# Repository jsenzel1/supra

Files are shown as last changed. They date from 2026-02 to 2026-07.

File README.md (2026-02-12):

# SUPRA
 [SUPRA](https://suprasynth.site/)

is multimode Eurorack module with 4 different experiments in long term time. you can run up to 2 modes at once. use the 4 way joystick and buttons to interact with the modes on the oled




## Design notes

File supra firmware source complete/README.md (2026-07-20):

# supra
supra synth

# NOTES 

note that the whole repo uses old naming conventions 

SQUIGL = STAMP 
SEQO = ABACUS
MORSD = CRYPTEX 
MELO = CHIME

Lots of stuff here is very messy and unoptimized 

## BUILDING

The firmware source and the library code it uses are included directly in this
directory. `u8g2/csrc`, `pico-littlefs/littlefs-lib`, and
`pico-littlefs/stdinit-lib` are vendored so this directory does not rely on
Git submodules.

Install the ARM embedded toolchain and Raspberry Pi Pico SDK, then point CMake
at the SDK. This source has been tested with Pico SDK 2.2.0.

```sh
cmake -S . -B build -DPICO_SDK_PATH=/path/to/pico-sdk
cmake --build build --parallel
```

The flashable firmware is written to `build/supra.uf2`.

AI DISCLOSURE 

This was a super ambitious project for me and parts of it required me to get a little beyond my abilities as a software engineer. I used AI for parts of the programming, I'm not sure how I feel about. I don't use AI to ideate or assist with design decisions, because I don't like doing that. I don't use it to whole cloth create something, because I don't like that. It's really nice to be able to offload tasks that I truly don't care about or have any artistic interest in how their done (Ie, 2 different ways to dim an LED, which I will explain later). Part of me wonders if it would have been better to be less ambitious and write more by hand, but that feels like its over emphasizing purity. Everything was at least prototyped by hand initially. most of the use of AI for programming was for stuff like the following situations: 

I had a lot of trouble using the DAC in supra with RP350 (my main chip) and after lots of troubleshooting I ended up using a proprietary driver that AI wrote to interface with the DAC because it worked where off the shelf libraries didn't (writing that myself would have been incredible hard, taken a long time, and not have been knowledge I would need in the future) 

I realized that because of a small quirk in the way I set up the hardware on the LEDs that one of them would not have dimming capabilities unless I redesigned and ordered a new batch, or if I implemented a software solution using PIO which is a more advanced feature of my main chip that I haven't gone into or learned about yet. So I had AI write it to save the time and materials of a new batch. 

I used AI to rewrite parts of the code that were innificient and to implement multithreading which I tried to do on my own but failed and was frustrated since It was a lot of work, and the only thing it would do is make things run smoother, so I wasn't doing anything artistic or interesting design wise. I decide dto allow myself to offload that task 

etc. etc.  

you will notice AI comments around the repo as I used AI to implement some features on many modes like self clocking etc. which would have been out of scope to add myself late in production

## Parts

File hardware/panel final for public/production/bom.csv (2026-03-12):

Designator | Footprint | Quantity | Value | LCSC Part #
C1, C6, C7 | 0402 | 3 | 100n | C1525
C2, C3, C4, C5 | 0402 | 4 | 100p | C1546
DAC1 | MSOP-10_3x3mm_P0.5mm | 1 | MCP4728 | C478093
J1, J2 | PinHeader_1x06_P2.54mm_Vertical | 2 | Conn_01x06_Pin
R1, R10, R13, R14, R2, R5, R6, R9 | 0402 | 8 | 100K | C25741
R11, R15, R3, R7 | 0402 | 4 | 270K | C170277
R12, R16, R4, R8 | 0402 | 4 | 1K | C11702
U1 | SOIC-14_3.9x8.7mm_P1.27mm | 1 | TL074 | C6963

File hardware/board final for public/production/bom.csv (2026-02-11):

Designator | Footprint | Quantity | Value | LCSC Part #
BT1 | BatteryHolder_Keystone_3000_1x12mm | 1 | Battery_Cell | C964818
C1, C15, C17, C18, C19, C2, C20, C21, C22, C23, C24, C28, C3, C30, C31, C4, C5 | 0402 | 17 | 100n | C1525
C10, C11, C12, C29 | 0402 | 4 | 10u | C15525
C16, C25, C26, C27 | 0402 | 4 | 4.7u | C23733
C8, C9 | 0402 | 2 | 27p | C1557
D1, D2 | D_SOD-123 | 2 | 5819 | C8598
D10, D11, D12, D13, D14, D15, D16, D17 | D_SOD-323 | 8 | BAT43W-V | C134399
D18 | LED_PLCC_2835 | 1 | Lselect | C7500124
D19 | LED_PLCC_2835 | 1 | Rselect | C7500124
D3, D4 | D_SOD-123 | 2 | SM4001 | C151781
D5, D7 | LED_PLCC_2835 | 2 | R2 | C7500124
D6 | LED_PLCC_2835 | 1 | L2 | C7500124
D8 | LED_PLCC_2835 | 1 | L1 | C7500124
DAC1 | MSOP-10_3x3mm_P0.5mm | 1 | MCP4728 | C108207
F1, F2 | 0805 | 2 | SMD0805P010TF polyfuse | C20975
J1 | _Jack_3.5mm_QingPu_JACK_ANCHOR | 1 | out 3
J10, J6, J7, J9 | _Jack_3.5mm_QingPu_JACK_ANCHOR | 4 | AudioJack2
J14 | _Jack_3.5mm_QingPu_JACK_ANCHOR | 1 | out 1
J2 | _Jack_3.5mm_QingPu_JACK_ANCHOR | 1 | out 2
J3 | USB_C_Receptacle_G-Switch_GT-USB-7010ASV | 1 | USB_C_Receptacle_USB2.0 | C2988369
J4 | PinHeader_2x05_P2.54mm_Vertical | 1 | Conn_02x05
J5 | PinSocket_1x04_P2.54mm_Vertical | 1 | OLED DISP
J8 | _Jack_3.5mm_QingPu_JACK_ANCHOR | 1 | out 4
L1 | L_pol_2016 | 1 | 3.3u | C42411119
R1, R10, R13, R14, R17, R20, R28, R4, R5, R6, R9 | 0402 | 11 | 1k | C11702
R11, R15, R3, R7 | 0805 | 4 | 400k
R12, R16, R2, R37, R38, R40, R42, R8 | 0402 | 8 | 100k | C25741
R18, R19 | 0402 | 2 | 5.1k | C25905
R21, R22, R30, R31, R33 | 0402 | 5 | 10k | C25744
R23 | 0402 | 1 | 33 | C25105
R24, R25 | 0402 | 2 | 27 | C25100
R26, R27 | 0402 | 2 | DNF
R29 | 0402 | 1 | 1k
R32, R34, R43, R44 | 0402 | 4 | 3.3k | C25890
R35, R36, R39, R41 | 0402 | 4 | 470 | C25117
R46, R47 | 0402 | 2 | 100r | C25076
S1 | sw_nav_5waySUPRA | 1 | JS5208
SW1 | SW_PUSH_6mm | 1 | btnBOOT
SW2 | SW_PUSH_6mm | 1 | btnA
SW3 | SW_PUSH_6mm | 1 | btnB
SW4 | SW_PUSH_6mm | 1 | btnHand
U2 | SOT-89-3 | 1 | LD1117S33CTR | C81768
U3 | SOIC-8_3.9x4.9mm_P1.27mm | 1 | PCF8523T | C2651516
U5 | SON50P300X200X60-9N | 1 | W25Q128JVS | C2843335
U6 | RP2350-QFN-60-1EP_7x7_P0.4mm_EP3.4x3.4mm_ThermalVias | 1 | RP2350_60QFN | C42411118
U7 | SOIC-14_3.9x8.7mm_P1.27mm | 1 | OPA1679 | C2878631
Y1 | Crystal_SMD_3225-4Pin_3.2x2.5mm | 1 | X322512MSB4SI (mini 12MhZ crystal) | C20625731
Y2 | Crystal_SMD_3215-2Pin_3.2x1.5mm | 1 | Crystal DST310S 32.768KHz | C93232

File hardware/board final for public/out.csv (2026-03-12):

Reference | Value | LCSC | Datasheet | Footprint | Qty | DNP | JLC
R29 | 0 |  | ~ | Resistor_SMD:R_0402_1005Metric | 1
C8,C9 | 27p | C1557 | ~ | Capacitor_SMD:C_0402_1005Metric | 2
C1,C15,C17,C18,C19,C20,C21,C22,C23,C24,C28,C30,C31 | 100n | C1525 | ~ | Capacitor_SMD:C_0402_1005Metric | 13 |  | -- mixed values --
C2,C3,C4,C5 | 100nf | C1525 | ~ | Capacitor_SMD:C_0402_1005Metric | 4
L1 | 3.3u | C695126 | ~ | RP2350_60QFN_minimal:L_pol_2016 | 1
C16,C25,C26,C27 | 4.7u | C23733 | ~ | Capacitor_SMD:C_0402_1005Metric | 4
C10,C11,C12,C29 | 10u | C25741 | ~ | Capacitor_SMD:C_0402_1005Metric | 4
R24,R25 | 27 | C25100 | ~ | Resistor_SMD:R_0402_1005Metric | 2
R23 | 33 |  | ~ | Resistor_SMD:R_0402_1005Metric | 1
R32,R34,R43,R44,R46,R47 | 100r | C25076 | ~ | Resistor_SMD:R_0402_1005Metric | 6
R35,R36,R39,R41 | 470 | C25117 | ~ | Capacitor_SMD:C_0402_1005Metric | 4
R1,R4,R5,R6,R9,R10,R13,R14,R17,R20,R28 | 1k | C11702 | ~ | -- mixed values -- | 11
R18,R19 | 5.1k | C25905 | ~ | Capacitor_SMD:C_0402_1005Metric | 2
D1,D2 | 5819 | C8598 | ~ | Diode_SMD:D_SOD-123 | 2
R30,R31,R33 | 10K | C25744 | ~ | Capacitor_SMD:C_0402_1005Metric | 3
R21,R22 | 10k | C25744 | ~ | Capacitor_SMD:C_0402_1005Metric | 2
R2,R8,R12,R16 | 100k | C25741 | ~ | Capacitor_SMD:C_0402_1005Metric | 4
R37,R38,R40,R42 | 100K | C25741 | ~ | Capacitor_SMD:C_0402_1005Metric | 4
R3,R7,R11,R15 | 400k |  | ~ | Capacitor_SMD:C_0402_1005Metric | 4
J6,J7,J9,J10 | AudioJack2 |  | ~ | Connector_Audio:_Jack_3.5mm_QingPu_JACK_ANCHOR | 4
D10,D11,D12,D13,D14,D15,D16,D17 | BAT43W-V | C134399 | http://www.vishay.com/docs/85660/bat42.pdf | Diode_SMD:D_SOD-323 | 8
BT1 | Battery_Cell | C964818 | ~ | Battery:BatteryHolder_Keystone_3000_1x12mm | 1
SW2 | btnA |  | ~ | Button_Switch_THT:SW_PUSH_6mm | 1
SW3 | btnB |  | ~ | Button_Switch_THT:SW_PUSH_6mm | 1
SW1 | btnBOOT |  | ~ | Button_Switch_THT:SW_PUSH_6mm | 1
SW4 | btnHand |  | ~ | Button_Switch_THT:SW_PUSH_6mm | 1
J4 | Conn_02x05 |  | ~ | Connector_PinHeader_2.54mm:PinHeader_2x05_P2.54mm_Vertical | 1
Y2 | Crystal DST310S 32.768KHz | C93232 | ~ | Crystal:Crystal_SMD_3215-2Pin_3.2x1.5mm | 1
R26,R27 | DNF |  | ~ | Resistor_SMD:R_0402_1005Metric | 2
U4 | ESP32-PICO-D4 |  | https://www.espressif.com/sites/default/files/documentation/esp32-pico-d4_datasheet_en.pdf | RPi_Pico:RPi_Pico_SMD_TH | 1
S1 | JS5208 |  |  | 4ms_Connector:sw_nav_5way | 1
D5,D8 | L1 |  | ~ | LED_SMD:LED_PLCC_2835 | 2
D6 | L2 |  | ~ | LED_SMD:LED_PLCC_2835 | 1
U2 | LD1117S33CTR | C81768 | http://www.st.com/content/ccc/resource/technical/document/datasheet/99/3b/7d/91/91/51/4b/be/CD00000544.pdf/files/CD00000544.pdf/jcr:content/translations/en.CD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 | Package_TO_SOT_SMD:SOT-89-3 | 1
D18 | Lselect |  | ~ | LED_SMD:LED_PLCC_2835 | 1
DAC1 | MCP4728 |  | http://ww1.microchip.com/downloads/en/DeviceDoc/22187E.pdf | Package_SO:MSOP-10_3x3mm_P0.5mm | 1 |  | C478093
J5 | OLED DISP |  | ~ | Connector_PinSocket_2.54mm:PinSocket_1x04_P2.54mm_Vertical | 1
U7 | OPA1679 |  | http://www.ti.com/lit/ds/symlink/opa1678.pdf | Package_SO:SOIC-14_3.9x8.7mm_P1.27mm | 1
J14 | out 1 |  | ~ | Connector_Audio:_Jack_3.5mm_QingPu_JACK_ANCHOR | 1
J2 | out 2 |  | ~ | Connector_Audio:_Jack_3.5mm_QingPu_JACK_ANCHOR | 1
J1 | out 3 |  | ~ | Connector_Audio:_Jack_3.5mm_QingPu_JACK_ANCHOR | 1
J8 | out 4 |  | ~ | Connector_Audio:_Jack_3.5mm_QingPu_JACK_ANCHOR | 1
U3 | PCF8523T | C2651516 | https://www.nxp.com/docs/en/data-sheet/PCF8523.pdf | Package_SO:SOIC-8_3.9x4.9mm_P1.27mm | 1
D7 | R2 |  | ~ | LED_SMD:LED_PLCC_2835 | 1
U6 | RP2350_60QFN |  |  | RP2350_60QFN_minimal:RP2350-QFN-60-1EP_7x7_P0.4mm_EP3.4x3.4mm_ThermalVias | 1
D19 | Rselect |  | ~ | LED_SMD:LED_PLCC_2835 | 1
D3,D4 | SM4001 | C151781 | http://cdn-reichelt.de/documents/datenblatt/A400/SMD1N400%23DIO.pdf | Diode_SMD:D_SOD-123 | 2
F1,F2 | SMD0805P010TF polyfuse | C20975 | ~ | Fuse:Fuse_0805_2012Metric | 2
J3 | USB_C_Receptacle_USB2.0 | C2988369 | https://www.usb.org/sites/default/files/documents/usb_type-c.zip | Connector_USB:USB_C_Receptacle_G-Switch_GT-USB-7010ASV | 1
U5 | W25Q128JVS | C2843335 | http://www.winbond.com/resource-files/w25q128jv_dtr%20revc%2003272018%20plus.pdf | Package_SO:SOIC-8_5.23x5.23mm_P1.27mm | 1
Y1 | X322512MSB4SI (mini 12MhZ crystal) | C9002 | ~ | Crystal:Crystal_SMD_3225-4Pin_3.2x2.5mm | 1

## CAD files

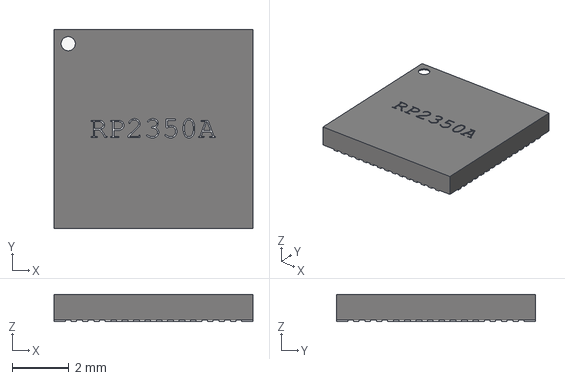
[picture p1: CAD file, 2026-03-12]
hardware/board final for public/RP2350_QFN60.step
7.00 x 7.00 x 0.95 mm

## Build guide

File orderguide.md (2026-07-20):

This is an ordering guide for SUPRA 
right now for internal use - but might be useful for people to see how it works 
note - if you need to order extra joysticks from adafruit its [this one](https://www.adafruit.com/product/504)

## STEP 1

order boards from JLC 
JLC boards and panels for production runs are always reorders to prevent alterations resulting in bricked runs 
more info and links for this coming, for now I'll probably be basically doing it 

## STEP 2 
order this cart from [mouser](https://www.mouser.com/Tools/Project/Share?AccessId=abbf7e4cee) 
you will have to select the items - this is for 100 modules, so the numbers can be changed accordingly 

PUBLIC NOTE: (this temp guide is for existing manufacturer ordering parts - so it doesn't include parts that are already stocked at their warehouse 
see [BOM](https://airtable.com/appK64nfCek7UE6Ky/shrHy2ZPqv2uyKhwK) for all parts 

## STEP 3

order this [display](https://www.buydisplay.com/i2c-white-1-3-inch-oled-display-module-128x64-arduino-raspberry-pi) from buydisplay 
note: fast shipping is extra but required for quick turnaround

## STEP 4 

order these [joystick toppers](https://www.amazon.com/uxcell-Silica-gel-Pushbutton-Tactile-Protector/dp/B07PGTZP9Z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) from amazon (RIP, literally cannot find them anywhere else and I have order lik $60 of various button toppers, these are the only that have worked at all) 

That should be it for now!

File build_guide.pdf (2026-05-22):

# Supra Build Guide

## 1: 5-way navigator

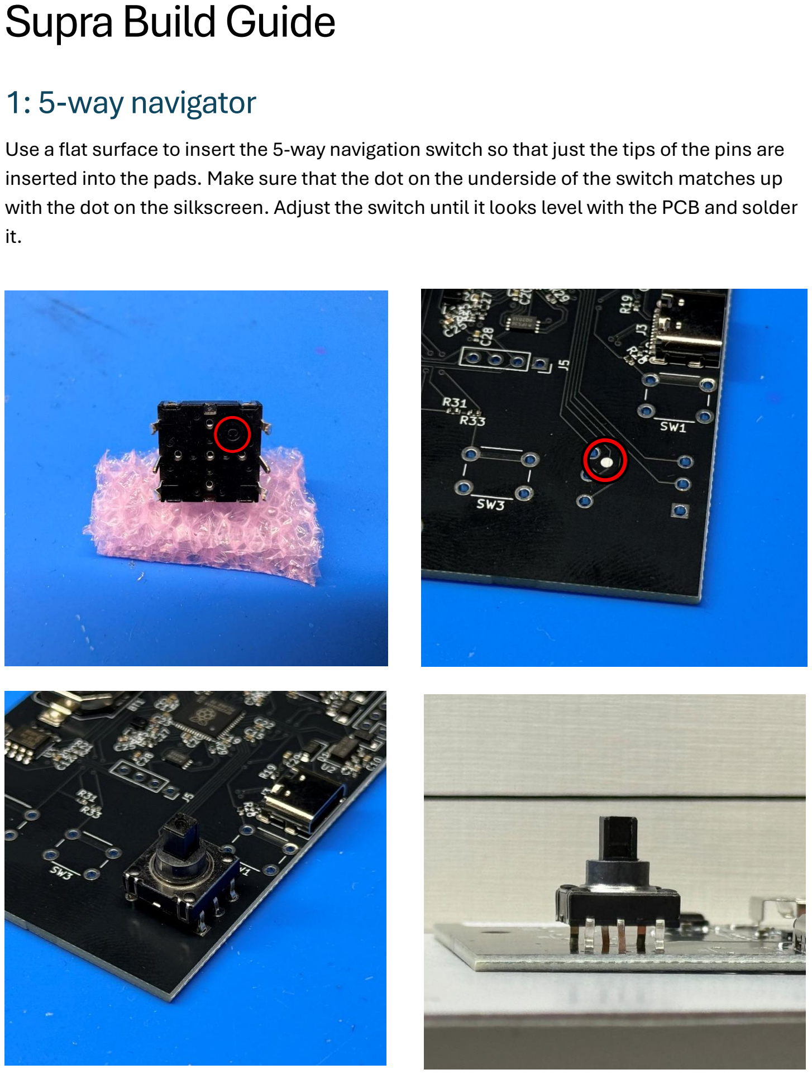
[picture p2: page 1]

Use a flat surface to insert the 5-way navigation switch so that just the tips of the pins are inserted into the pads. Make sure that the dot on the underside of the switch matches up with the dot on the silkscreen. Adjust the switch until it looks level with the PCB and solder it.

## 2: Pushbutton and power header

On the back side of the PCB, insert the pushbutton and power header. When soldering the power header be mindful of the surrounding surface mount components.

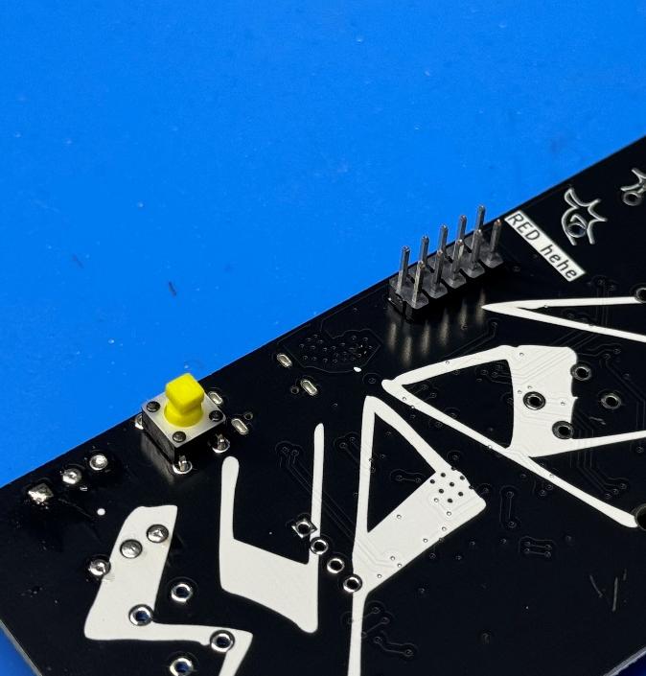
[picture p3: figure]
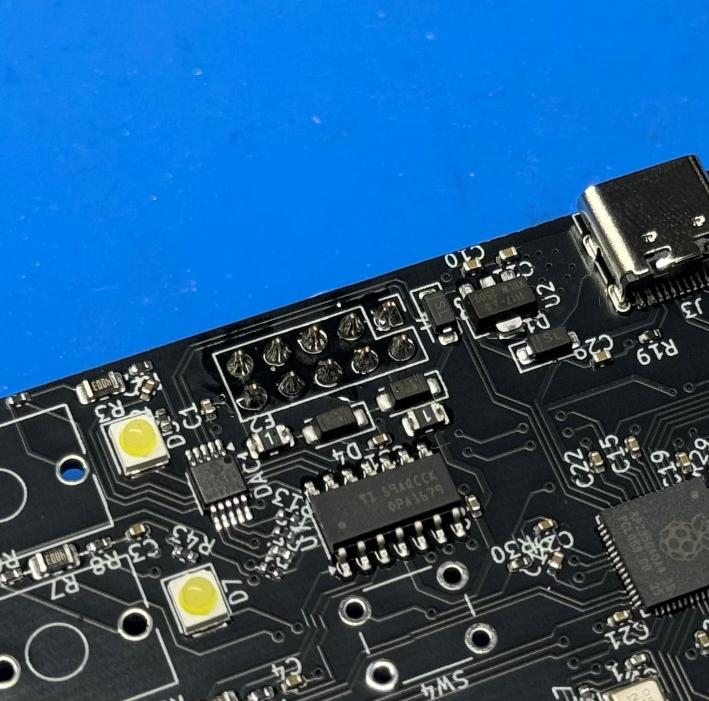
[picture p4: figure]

## 3: OLED display

To mount the display, you will need the included 6mm spacer, the 4mm screw, and a hex nut. Attach the spacer the bottom of the display with the screw and insert the pins and threaded end of the spacer in the PCB. Use the hex nut to secure the display. Adjust the display until it looks parallel to the PCB and solder the pins. At this point you can remove the screen protector.

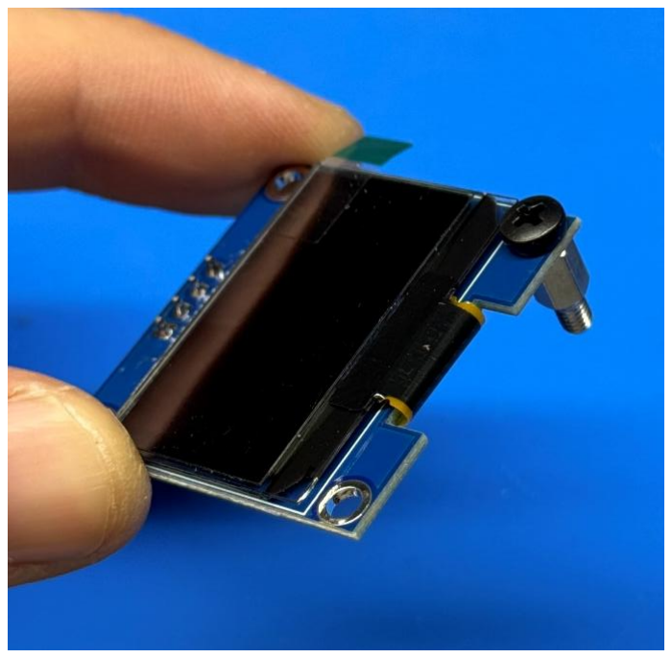
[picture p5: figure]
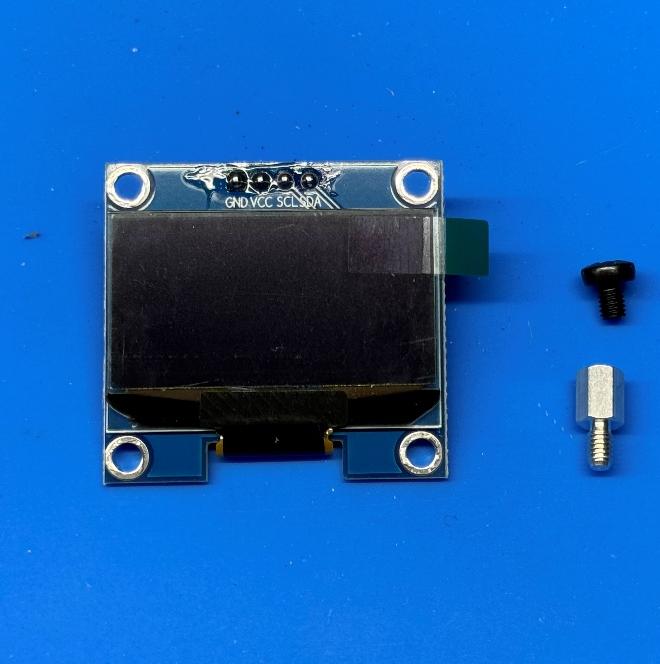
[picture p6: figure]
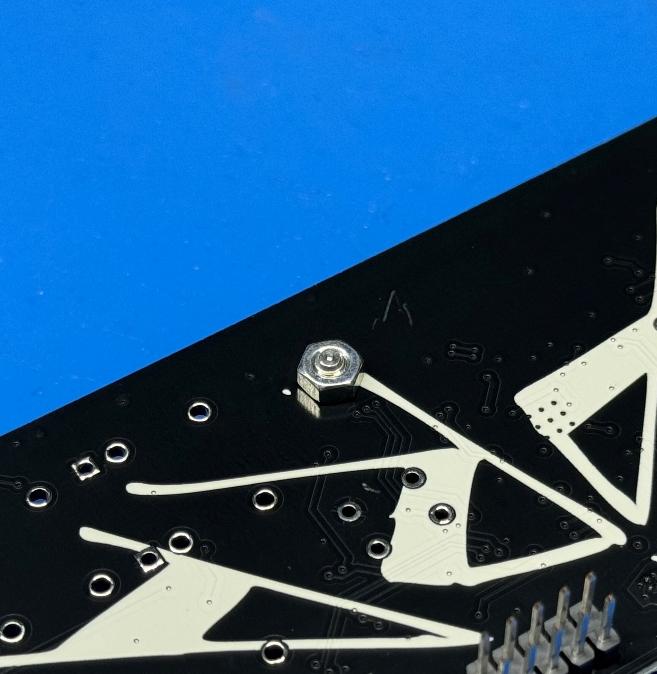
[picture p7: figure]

## 4: Panel hardware

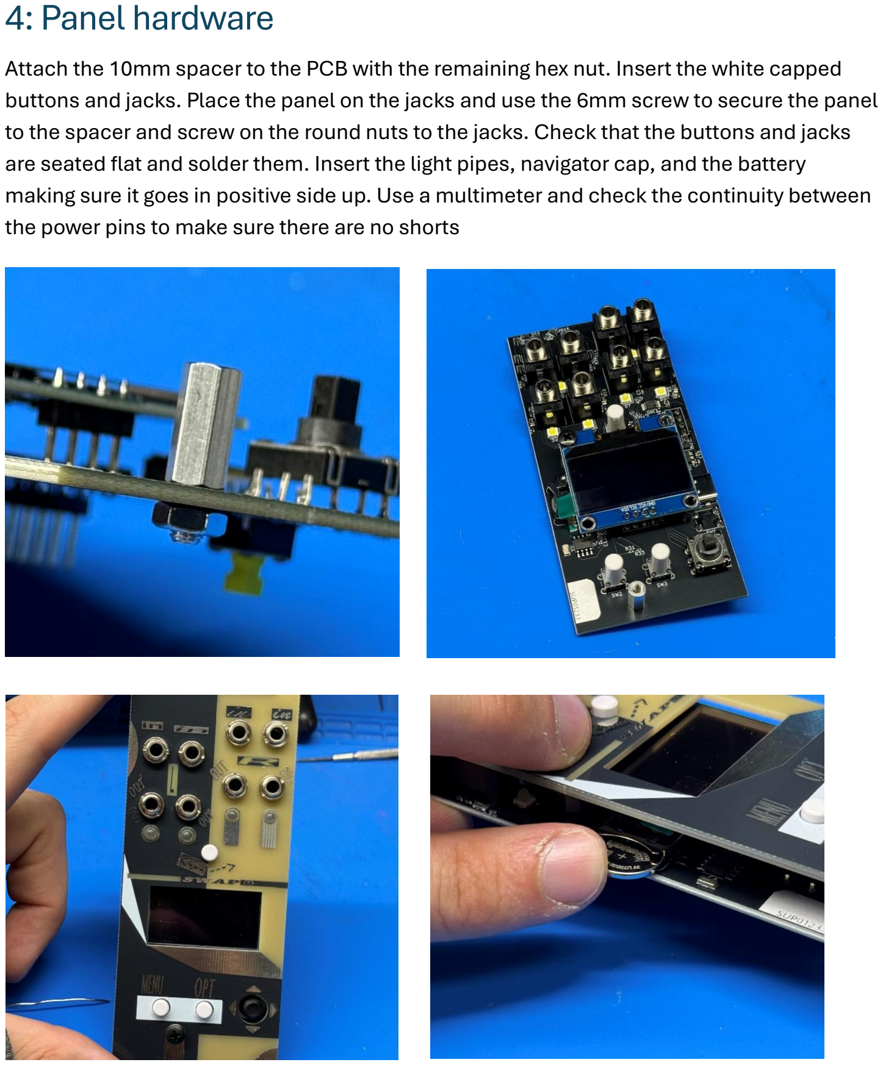
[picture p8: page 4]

Attach the 10mm spacer to the PCB with the remaining hex nut. Insert the white capped buttons and jacks. Place the panel on the jacks and use the 6mm screw to secure the panel to the spacer and screw on the round nuts to the jacks. Check that the buttons and jacks are seated flat and solder them. Insert the light pipes, navigator cap, and the battery making sure it goes in positive side up. Use a multimeter and check the continuity between the power pins to make sure there are no shorts

## 5: Computer stuff

Plug your Supra into your computer with a USB C cable. Flash the Supra and set the current date and time with the navigator.

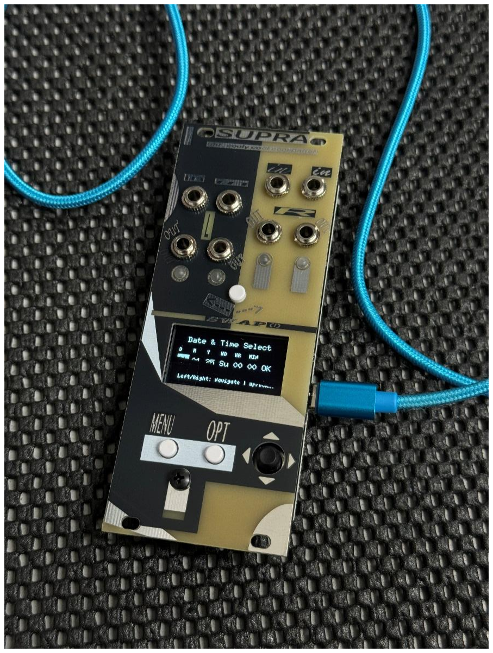
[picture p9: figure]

6: Yippee!
Plug your Supra into your system and check to see if the button, inputs, and outputs are working correctly. Congratulations, you finished your Supra! Have fun getting lost in supratime!

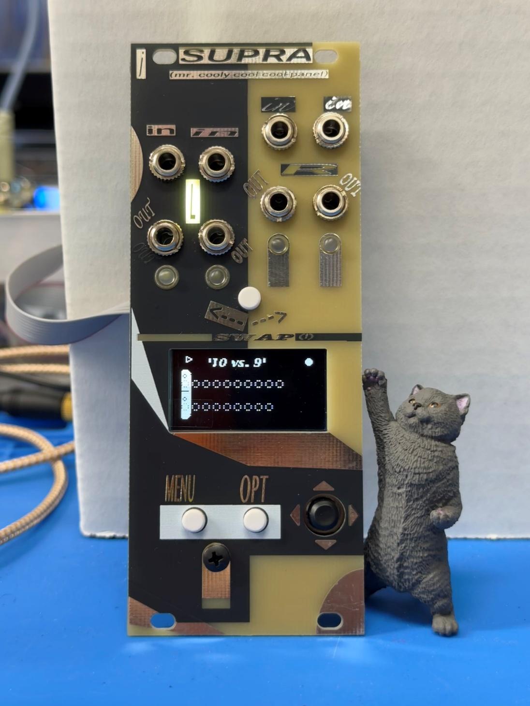
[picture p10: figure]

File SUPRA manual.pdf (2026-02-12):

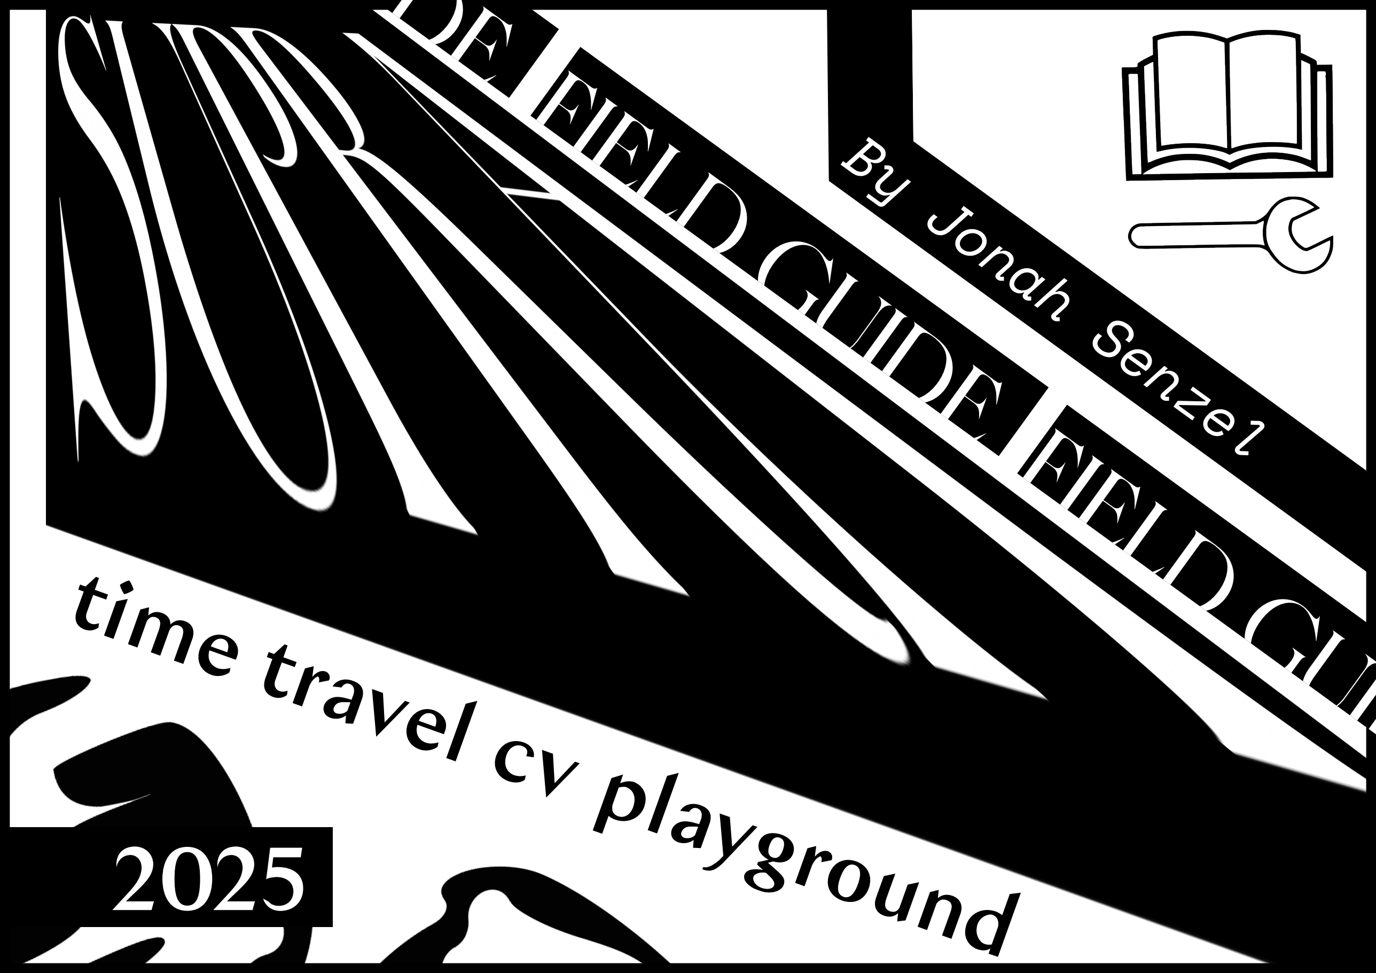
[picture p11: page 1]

# Field Guide

# time travel cv playground

# By Jonah Senzel

2025

# Field Guide

de

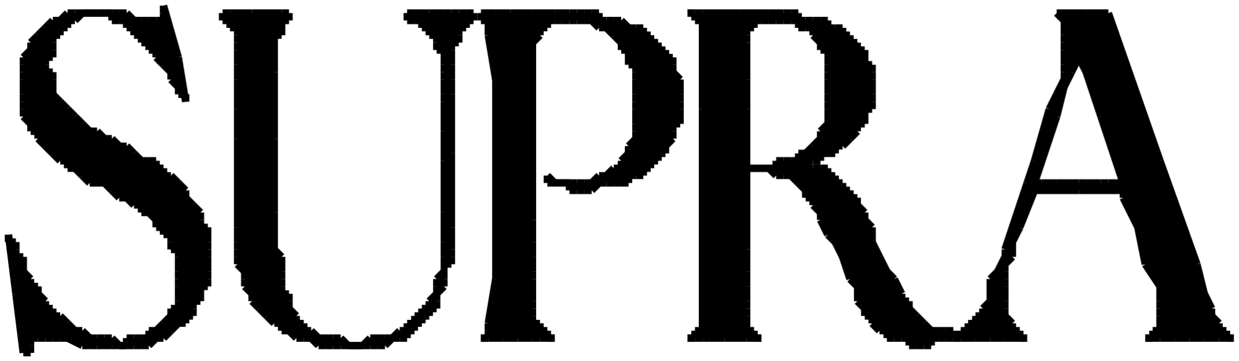
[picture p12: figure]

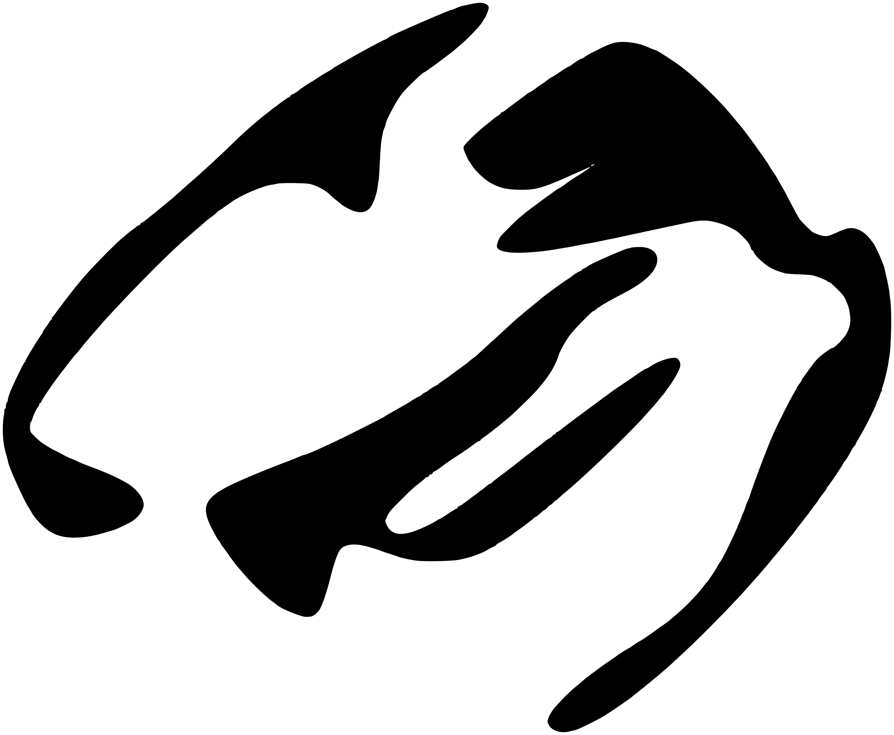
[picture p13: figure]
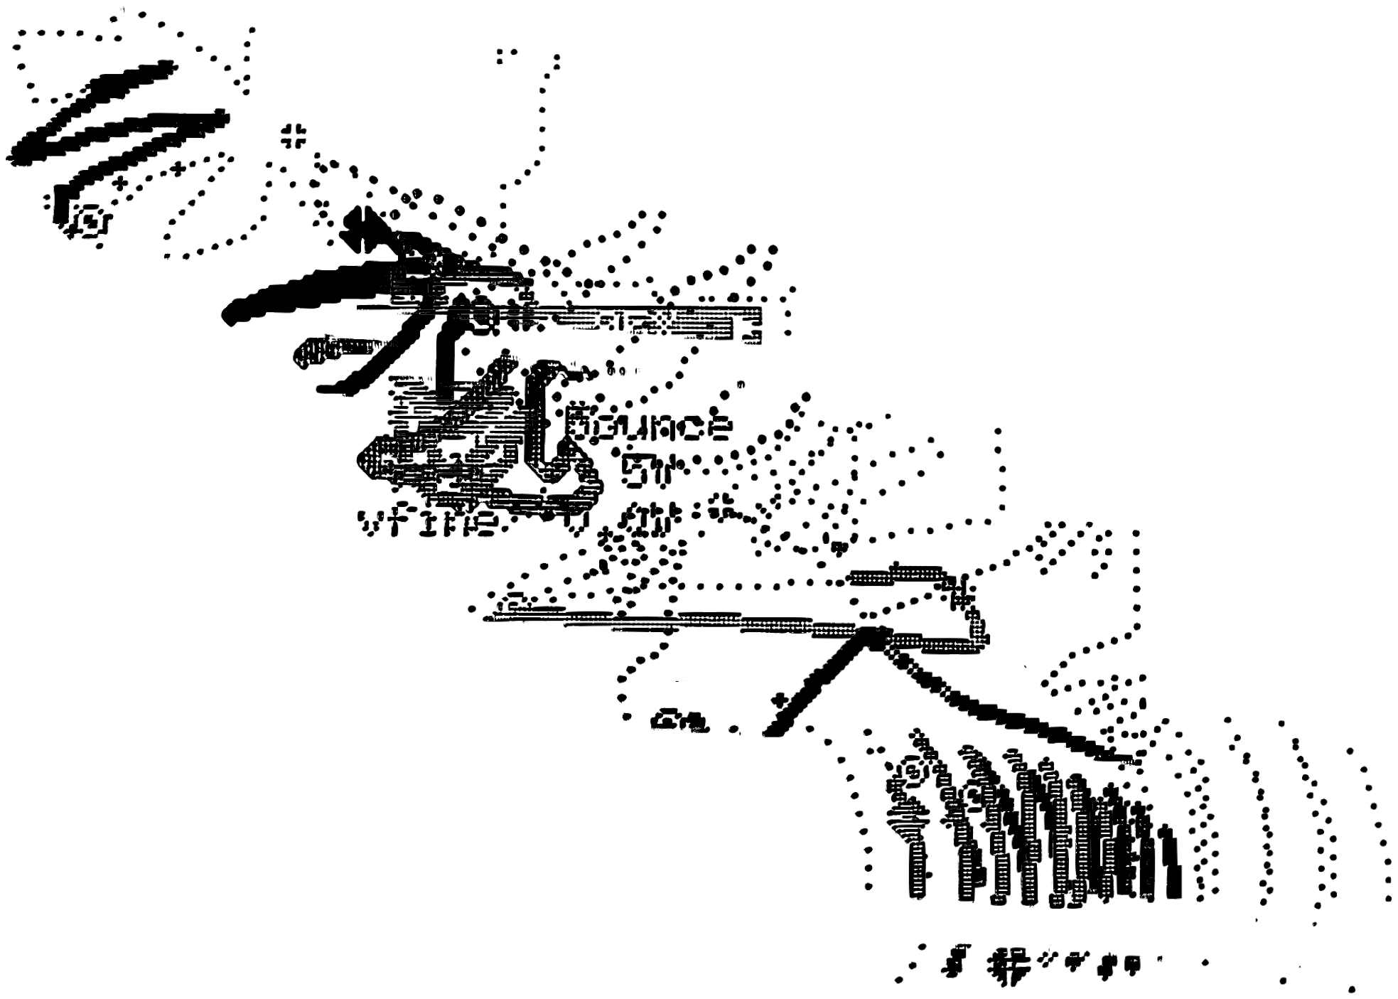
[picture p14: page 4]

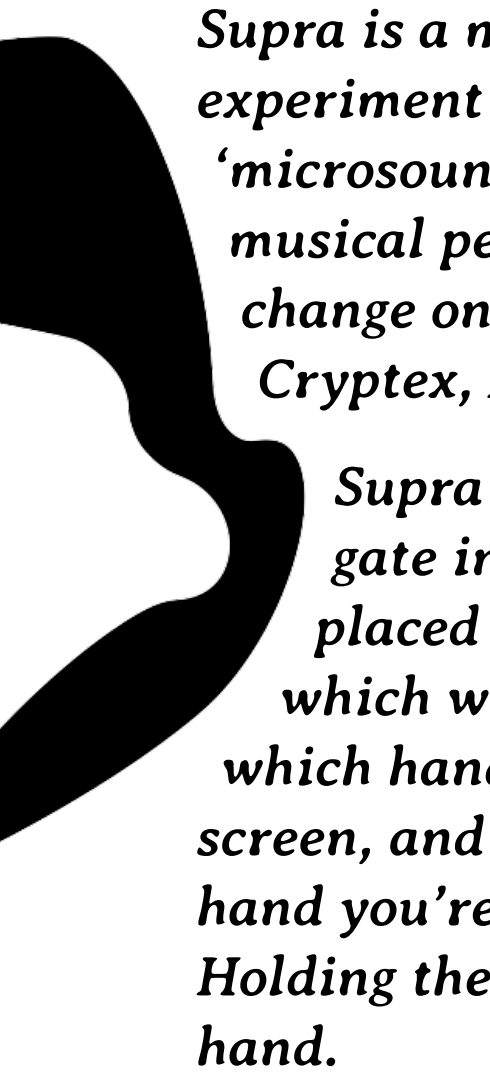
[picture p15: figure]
hand.

Supra is a multimode module with 4 modes. Each mode is an experiment in ‘supra-time’ a term coined by Curtis Roads in ‘microsound’ to describe changes that happen at the scale beyond one

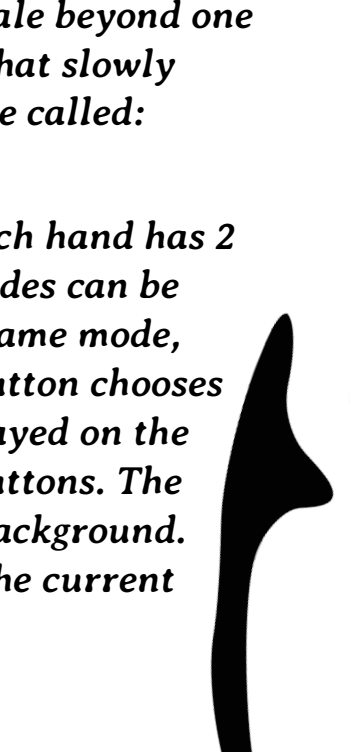
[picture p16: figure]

musical performance or event. Supra is a set of tools that slowly change on their own very slow timeline. The modes are called: Cryptex, Abacus, Stamp, and Chime.
Supra is divided into 2 “hands” Left and Right. Each hand has 2 gate inputs and 2 gate/cv outputs. Any of the 4 modes can be placed into either hand (including 2 copies of the same mode, which will operate independently). Pressing swap button chooses which hand you’re ‘looking at’ meaning which is displayed on the screen, and controlled by the joystick, menu, and opt buttons. The hand you’re not looking at will continue to run in the background. Holding the swap button lets you place a new mode in the current

# OVERVIEW

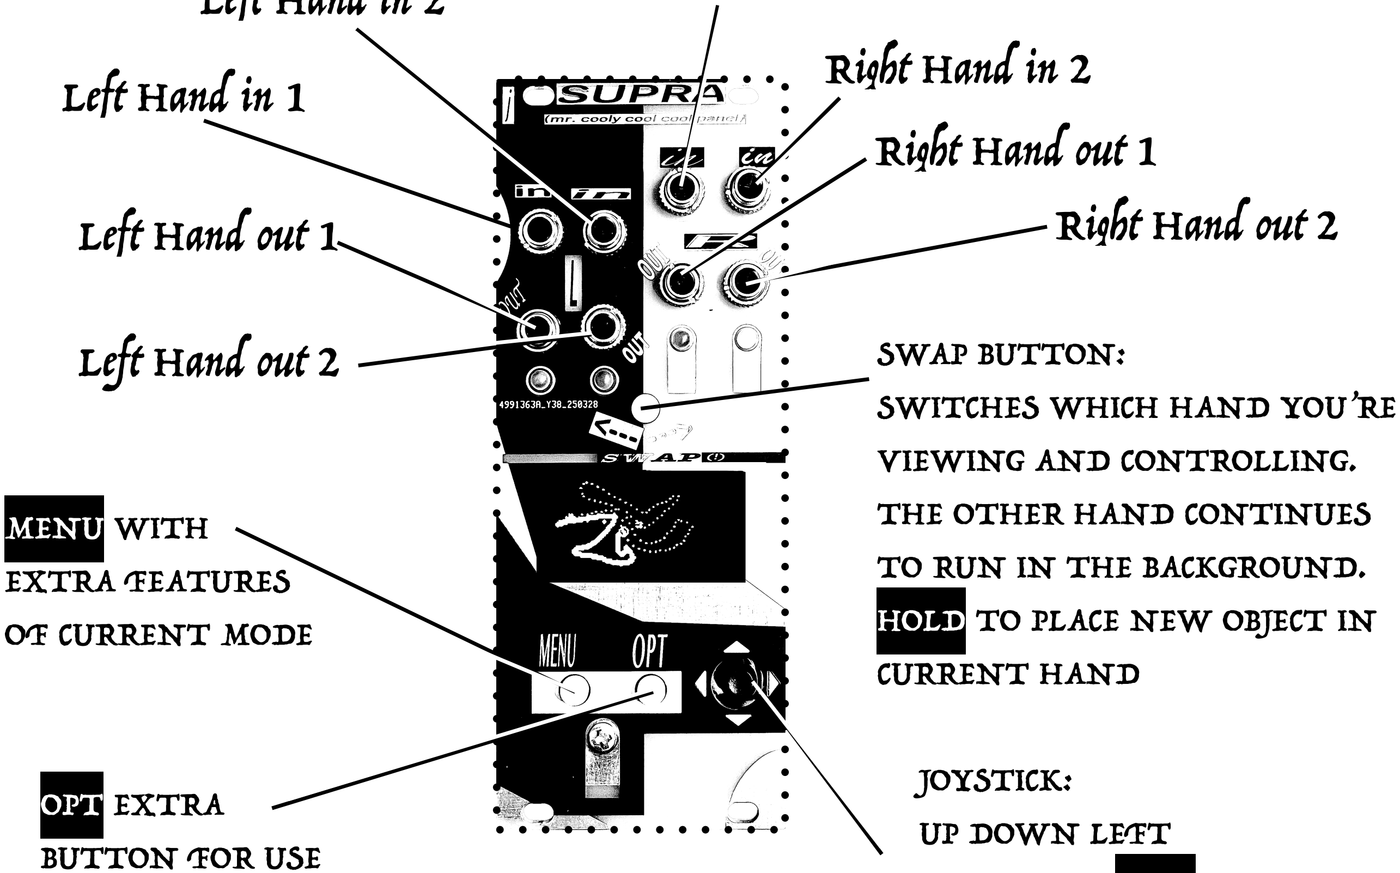
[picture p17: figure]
Left Hand out 1 Left Hand out 2; Right Hand in 2 Right Hand out 1; MENU WITH EXTRA FEATURES OF CURRENT MODE; SWAP BUTTON: SWITCHES WHICH HAND YOU’RE VIEWING AND CONTROLLING. THE OTHER HAND CONTINUES TO RUN IN THE BACKGROUND. HOLD TO PLACE NEW OBJECT IN CURRENT HAND; OPT EXTRA; JOYSTICK: UP DOWN LEFT

# Left Hand in 1

# Left Hand in 2

# Right Hand in 1

# Right Hand out 2

# SUPRA

## BUTTON FOR USE IN SOME MODES

## RIGHT AND CLICK (PUSH IN )

## Morse code translation rhythm scavenger

# cryptex

Cryptex is an encoded epoch scale reading of Homer’s Odyssey. Every 3 hours, 3 new words from the Odyssey are displayed (in order), alongside their morse code translations. The user can then select portions of the translation to loop through as dot-dash based gate rhythms, and rotate the entire translated sequence to change which part plays in the loop

Controls:
- Joystick rotates the entire sequence, changing what is inside of the looped section
- Joystick click switches to edit mode, use | to
move the loop point around, changing the sequence length

In 1: clock .
in 2: reset
out 1: sequence gates
out 2: in split mode outputs dash gates (out1 is dot gates)

### Dots

E .
I ..
S ...
H ….

### Dashes

T -
M --
O ---

### Just C

C -.-.

### Dot Dashes

a
A .-
W .--
J .---

### Dash Dots

a
N -.
D -..
B -...

### Dash Sandwiches

a
R .-.
P .--.

### Dot Sandwiches

a
K - . -
X - . . -

### Double Dashes

a
G --.
Z --..

### Double Dots(um or 3)

a
U ..-
V ...-

### Jumping Dashes

a
L .-..
F ..-.

### Crouching Dots

a
Y -.--
Q --.-

# STAMP

# Graphical Rail Riding CV Generator

Stamp generates CV by tracing a portion of an image in a loop. As the outline of the image is traced, the closer the tracing point is to the center of the screen, the higher the voltage. Also, the closer the tracing point to the center, the faster it moves (this attraction forced is called gravity). Stamp contains 365 drawn images, a different one shown for each day of the year.
Controls: (in relation to the ‘head’ of the loop which looks like this:
right extends the length of the loop, moving away from the head
left shortens the length of the loop, moving towards the head
up shifts the position of the loop along the image, towards the head down shifts the position of the loop along the image, away from the head
In 1: reset loop (see menu reset modes) | In 2: n/a | out 1: CV value | out 2: n/a

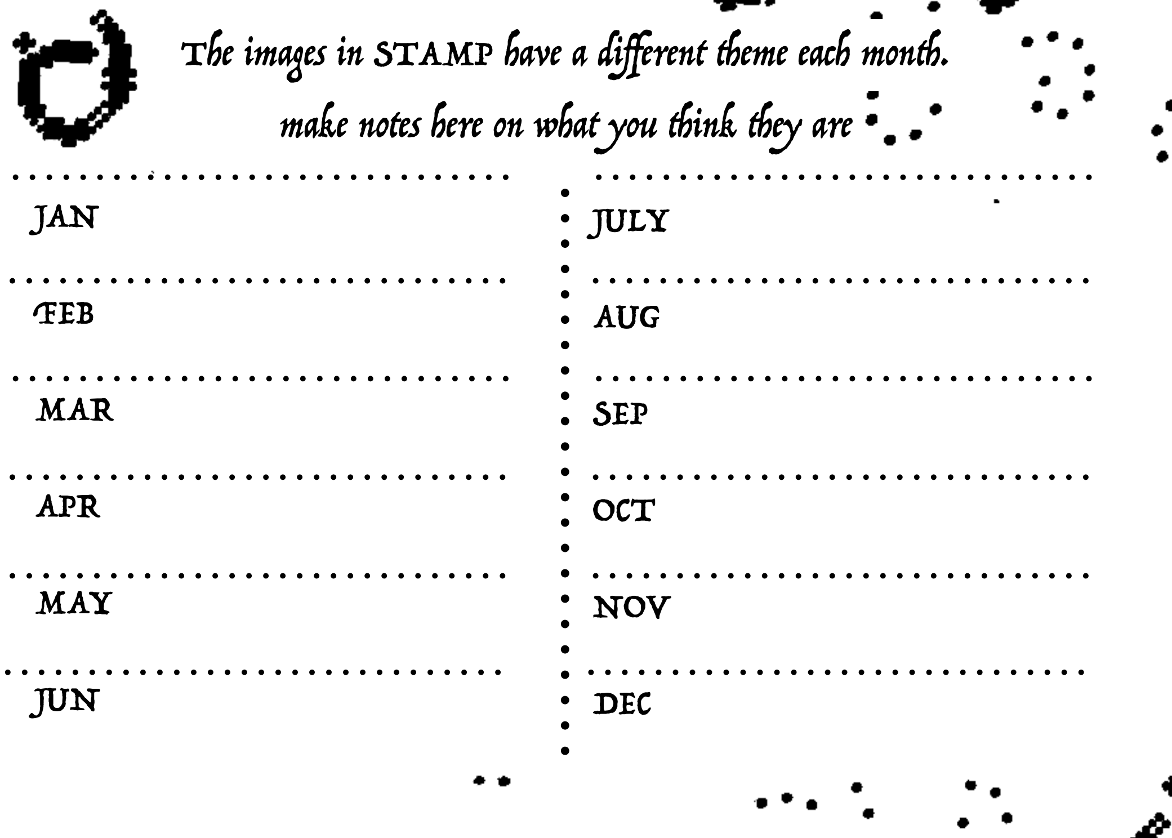
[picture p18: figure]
JAN FEB MAR APR MAY JUN; JULY AUG SEP OCT NOV DEC

The images in STAMP have a different theme each month.

# make notes here on what you think they are

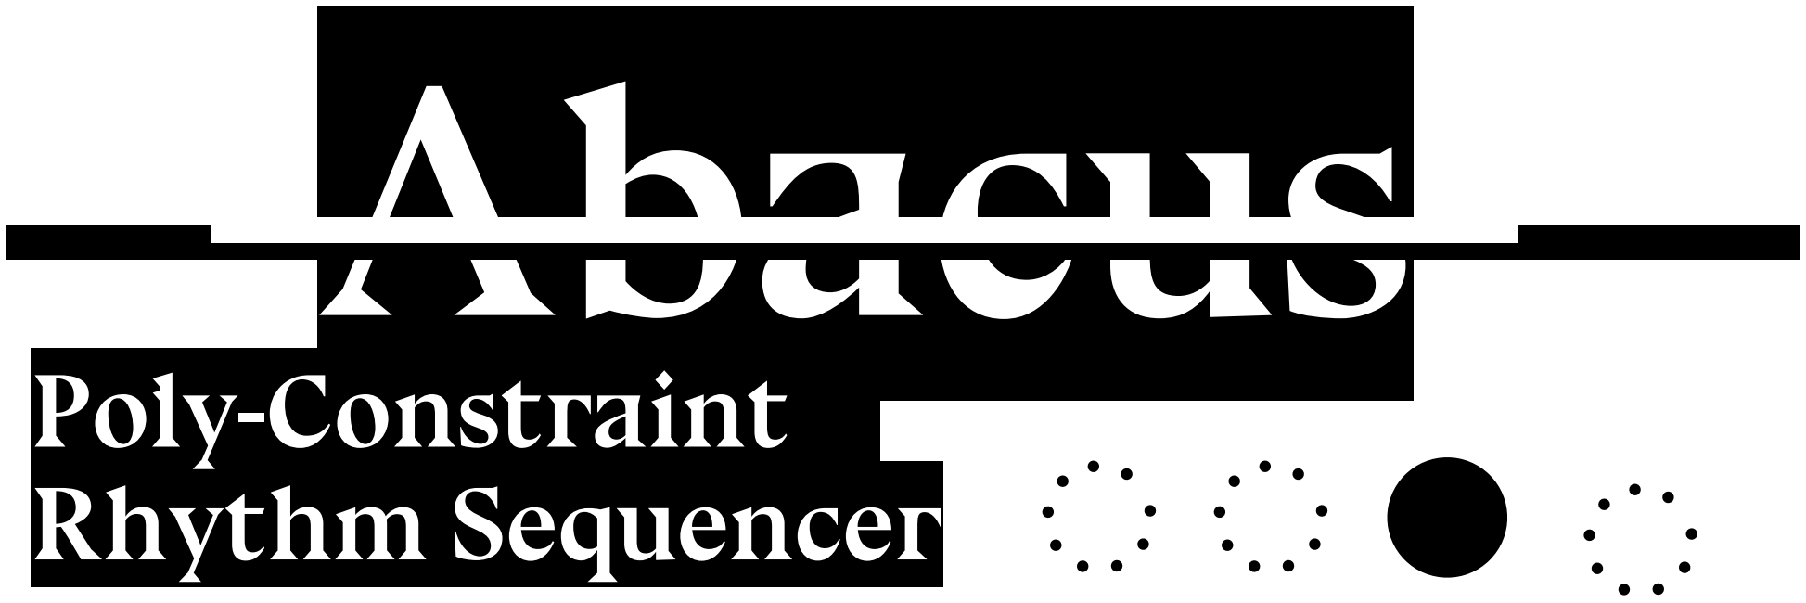
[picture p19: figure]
Abacus; Poly-Constraint Rhythm Sequencer

Abacus Is a Step Sequencer. Each day you get 2 new blank sequences of a random length to place steps in. You also get one special ‘skip-step’ type per day to place in your sequences.
Use joystick | to navigate inside of a sequence and click to add,
or remove the current step. Use | to navigate between the two
sequences. Press OPT | to switch between placing normal steps
and placing your skip-step (shown in top left) which will only play every 2nd, 3rd, etc. time its passed (depending on the type)
In 1: clock. | in 2: reset | out 1: sequence 1 gate | out 2: sequence 2

Time for some math! With 2 sequences of set length, simply multiply their lengths to determine how many input pulses it takes to have them sync back up on step one. So for lengths 8, and 5 - every 40 input pulses they will be synced on step 1. Skip steps of course complicate this and allow for combinatorially complex rhythms.
Use the circle grid to work out Abacus math and simulate rhythms

# CHImE

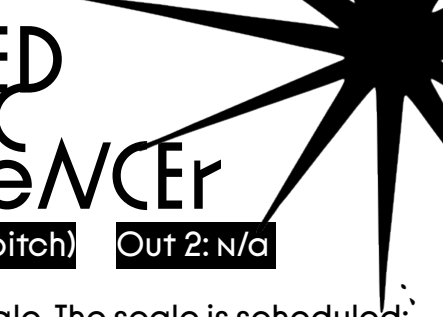
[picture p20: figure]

Chime lets you sequence notes within a provided scale. The scale is scheduled: each day of the week has 2 scales, one for before noon, and one for after noon. So, every Friday morning will have the same scale, and every
Wednesday evening, etc. When a season changes, ie, on the first day of spring, all of the scales in the schedule are swapped out with the scales selected for that season. So there are 14 weekly scheduled scales, and 4 banks of scales,

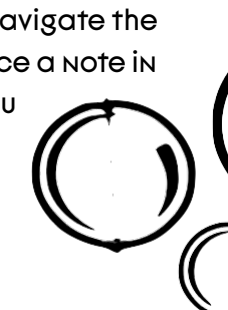
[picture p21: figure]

one for each season (56 total scales). Use joystick | to navigate the
top library section (the top section is upper octave) click to place a note in

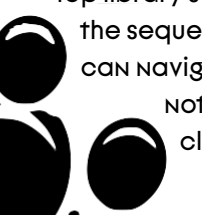
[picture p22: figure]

the sequence. Pressing opt switches to ‘edit’ mode in which you
can navigate within the sequence, and click to ‘pick up’ a
note (which will start flashing) and move it around, clicking again to place the note back down

# SCHEdULizED mELODiC sEqUeNCEr

In 1: clock | In 2: reset | Out 1: sequence cv (v/oct pitch) | Out 2: n/a

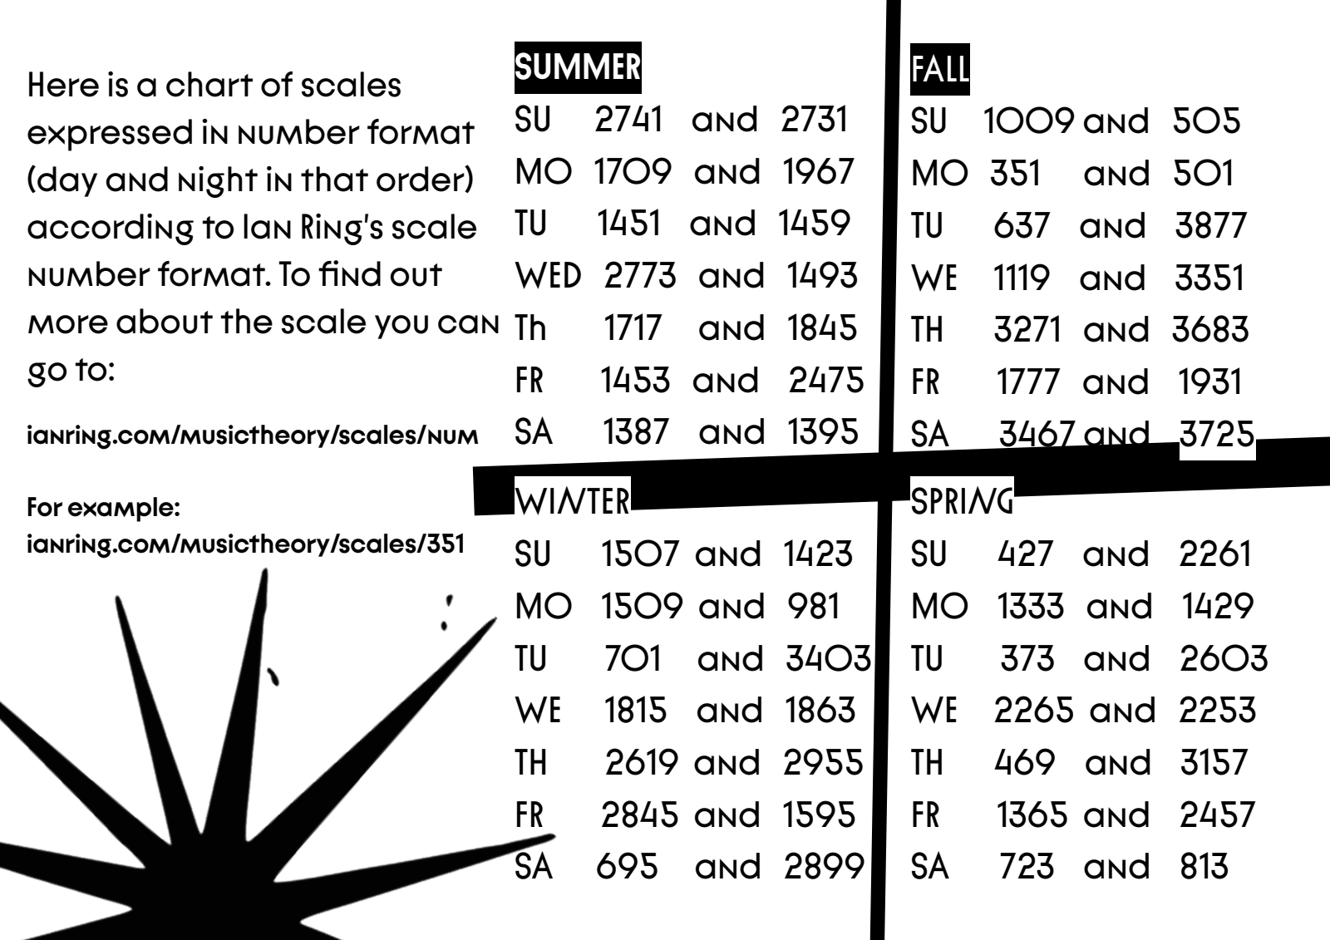
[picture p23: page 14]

Here is a chart of scales
expressed in number format (day and night in that order) according to Ian Ring’s scale number format. To find out more about the scale you can go to:

ianring.com/musictheory/scales/num

For example:
ianring.com/musictheory/scales/351

WINTER
SU 1507 and 1423
MO 1509 and 981
TU 701 and 3403
WE 1815 and 1863
TH | 2619 and 2955
FR | 2845 and 1595
SA 695 and 2899

SUMMER
SU 2741 and 2731
MO 1709 and 1967
TU 1451 and 1459
WED 2773 and 1493
Th | 1717 and 1845
FR | 1453 and 2475
SA | 1387 and 1395

FALL
SU 1009 and 505
MO 351 and 501
TU 637 and 3877
WE 1119 and 3351
TH | 3271 and 3683
FR | 1777 and 1931
SA | 3467 and | 3725
SPRING
SU 427 and 2261
MO 1333 and 1429
TU 373 and 2603
WE 2265 and 2253
TH | 469 and 3157
FR | 1365 and 2457
SA | 723 and 813

time is weird - I had bigger ambitions for supra but the release is a month out when

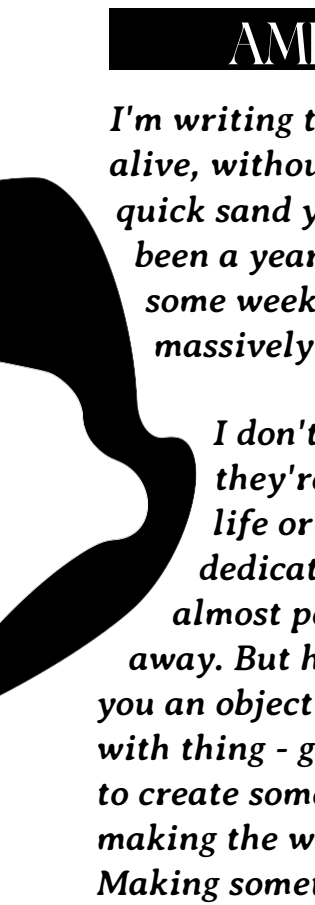
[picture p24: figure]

I'm writing this and I've got to put something out - deadlines keep me alive, without them there's just infinite sludge, goopy time that can quick sand you. I had set the release date a year ago in my mind - it's been a year 1/2 development - some months are 95% thumb twiddling,

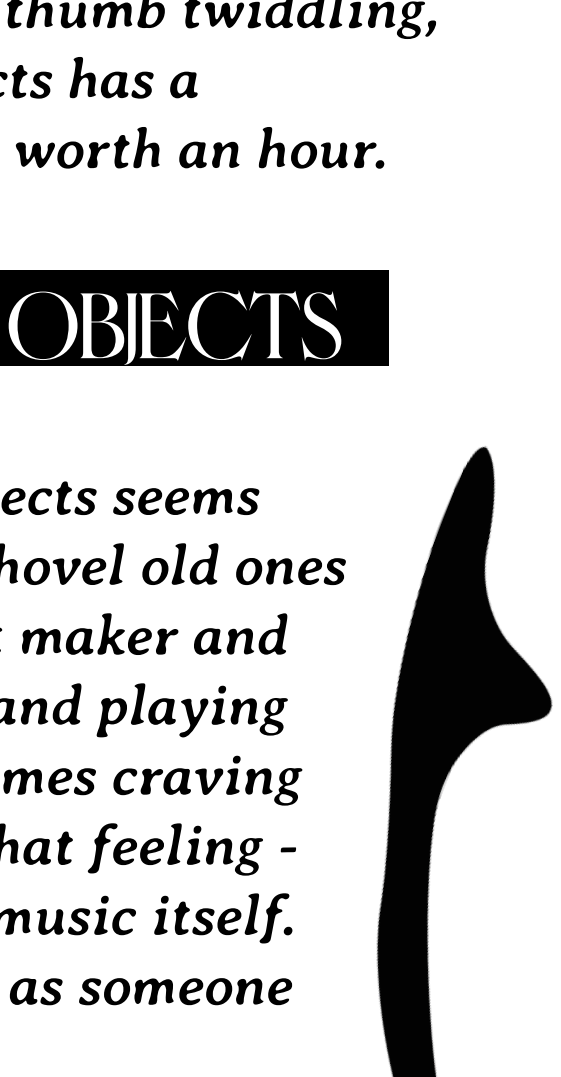
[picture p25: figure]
OBJECTS

some weeks produce months of work. Time in projects has a massively fluctuating exchange rate - an hour isn't worth an hour.

# AMBITIONS

I don't really 'believe' in Objects -
they're not a truly important part of
life or at least not what I want to
dedicate my time to. Especially creating new objects seems almost perverse, let alone new electronics as we shovel old ones away. But here we are, I've found myself as the objet maker and you an object consumer. What I love is making music, and playing with thing - games and systems. I've found myself at times craving to create something that beckons play - that induces that feeling -making the world in which the music is made, not the music itself. Making something for the people that make. I felt that as someone

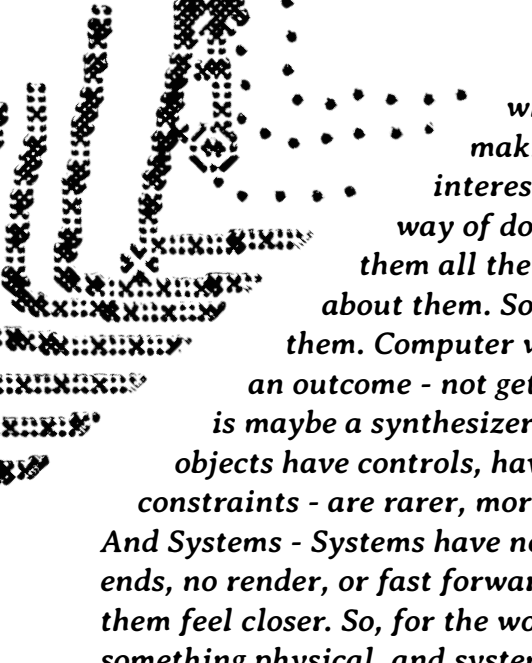
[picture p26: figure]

who has spent a lot of time in different making worlds, that I could say something interesting with one of my own. I could inform a way of doing. Digital objects are amazing and I use them all the time, but there's something disposable about them. Something inherently practical tasting about them. Computer worlds for making bias towards producing an outcome - not getting lost in the messing-aroundery, which is maybe a synthesizer's most valuable offering. Physical making objects have controls, have form, have harder decisions so more constraints - are rarer, more valuable by way of meat space attention. And Systems - Systems have no timeline of bars, no official starts and ends, no render, or fast forward, or undo - an impracticality that makes them feel closer. So, for the world I wanted to express, I needed something physical, and systems based. And thus I arrived at Eurorack -as imperfect as it is, one of the few places which allowed playing in a physical system.

# DEVELOPMENT LOG

These are some little notes I made thinking back on each object in Supra, and how it was developed, what my life was like, the challenges etc.

CRYPTEX - Dec 2023
Cryptex was the first mode for supra, so its hard to remember when what started. I had a back of the brain interest in morse code - a friend made a morse code game about sinking ships by tapping out codes on a real key - i made a little pico-8 morse code sketch - i used morse code in a piece of music for work as a way to hide a secret from the developer. I liked the endless combination of rhythms made up entirely of the stilted pulses 1 or 3 counts long, which feels so different than how we usually think of rhythms. And i liked the idea of sifting through a pile of stuff, finding your own rhythms in the heap - creating through curating. I started working on cryptex while moving around a lot - in the Netherlands, Greece, New York - makes it feel like I’ve been working on it for so many years. The visual style i owe entirely to AC - I was showing him the mode at the time, really frustrated with some technical bug, and he just looked at it for one minute and then scribbled out a little diagram and said “maybe it could look like this” - i was really annoyed at the time because i didn’t want to deal with polish or visuals until later, but i ended up basically just recreating his sketch, and that visual style directs the way you engage with the mode beyond aesthetics. What the text should be was a big question mark for a really long time - at the very end of development i started to look for non copyrighted works that i could use, and the odyssey seemed so perfectly symbolic of length as a concept (and it has a lot of interesting/weird words). Im pretty happy with how cryptex turned out - theres something rhythmically significant about the way morse code sounds. Its the only class of rhythm that i can think of that might be so uniquely recognizable by non musicians - it has a cadence that we know, if more by feel than technical knowledge.

ABACUS - 2024 (late winter, early spring)
It's hard to remember when I actually started abacus - I remember working on it alongside AC and another friend, all doing wildly different projects - we all had desks in our common space, a super long thin apartment. I would sit and play with my prototype, going back and forth tweaking things about it. There's something magical about a rhythm in 2 parts, it's just perfect, something is very natural feeling about it. Abacus is a sort of successor to my first module Pet Rock, which generated a dual channel rhythm per day. I wanted it to serve as a marker of what I was trying to do with Supra - generating a tool to play with, rather than generating the content itself. Years ago I had sat with a little Swedish synth not to be named, and played with a sequencer mode with 2 oddly lengthed sequences, which I would try to randomly set, and then create patterns within. Abacus is basically an attempt to recreate that experience. I wanted something with simple design, where the fun came from you.

STAMP - summer 2024
Spring 2024 was rough - I was really sad about life things, and trying to make progress on the supra but doing more sitty aroundey tweakey work than anything real. In July I took a big pacific northwest trip visiting friends along the coast in Vancouver, Seattle and Portland. The trip made me feel better about a lot of things. I suddenly felt less stagnant, more curious again. I was sort of just absorbed in the environment, especially in vancouver - a lot of nice emptier time there, wandering long, and looking a things in the city - I went and camped on the tiny Keat's Island, off of the sunshine coast (shout out to the ferry white spot). I took the amtrak down to Seattle, right on the ocean, with a huge golden sunset, edge to edge in the big spread windows. That is to say, that I arrived in Seattle refreshed, if not some more dramatic word. My brain was ready to think upside down again. I stayed there at a friend's house studio, and accompanied him to his office one day which was kind of a bungalow of friends. There everyone was doing actual work, so I tinkered away on supra. I had been dipping my toe into bitmap images and pulled up the code. I wanted to start working on something that used cv not just gates, and I started playing there with how an Image's edge could be detected and traced if it was drawn correctly by hand. I drew a test image and by the end of the afternoon I had the visual framework and gravity movement of stamp working. It was such pure fun, translating something I had drawn into the world of the machine. Through the course of development represented more technical work and issues than anything else in the module, and the technical parts went through a lot of painful iterations - but I think it's the most *fun* mode - it's the best toy, and that's important, and makes me happy.

CHIME - summer 2024
A lot of the time after chime was sort of a hail mary mode. I wanted to have another mode that uses cv, and it took sooooo much longer to get stamp working than I expected. Then a lot of the time after that was spent designing and iterating the hardware - everything up to that point was made on a little piece of prototype board with off the shelf stuff. I had been away from programming as my main task for a bit. I knew that 4 was the absolute minimum for a multimode module in my head, so I started frantically working on chime last minute. The idea for time of day effecting scales was in the back of my mind for a long time, based on the concept from indian Raga. I played around with the scale being a random collection of notes, but that just didn't sound very good. I found this amazing site that compiles every conceivable scale and that set off the idea that the scales should be authored/picked. Chime has been the most thrown together mode for sure - everything has been on a too tight timeline, but I think it plays quite nicely with the rest of Supra. It makes the module a lot more versatile and provides a lot of combinatorial opportunities. I worked on chime alongside my friend Karp, mostly silently and frustratedly. It being the last mode also made me a little sad because at some point i envisioned more like 8 modes for supra, but alas, the module had to come out. Thinking about chime makes me feel stressed out hehe

The end of Supra development has been sort of a shit show. I left things too late, and have been scrambling to finish everything - I hate making decisions, so a lot of end of the line decisions had to be made, and then implemented. Oops! Guess it always feels like that to some degree, but it's been a wild ride - I'm not even finished as I write the manual. Here's hoping for the best :)

# More Ramblings

What to do about cost? I released my first module 'Pet Rock' at cost of production - and Supra is sold at about cost of production (I've learned it's very difficult to reach perfect equilibrium - but no money goes back to me, anything more goes into more modules and development, anything less gets taken from that pool). I have the luxury of a fancy (and very fun) composition job which means

I live comfortably completely outside of Eurorack - most makers don't have that. A lot of people misunderstand that I think everyone should sell at cost. That feels unfair to expect. What I do expect is for makers to acknowledge that Eurorack inaccessible and find a way to help change that

ways we change eurorack:

if you have financial stability - start designing modules because you want to, not to start a business. Sell cheaper. (could be double cost of production even, that's still often well below market rate). It also feels better because you're not tracking profit constantly, so
you make what you want, and how much of it you want.

publicize costs/finances

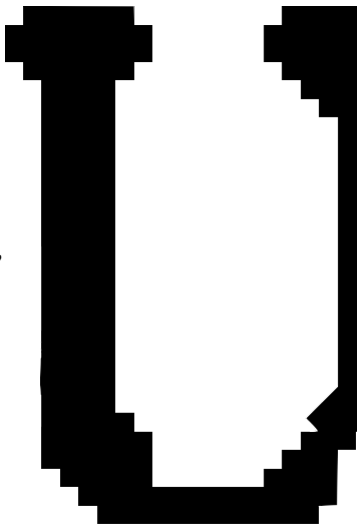
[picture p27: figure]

Transparency breeds accessibility. Most people don't really understand what a module actually is (a circuit board, panel, and components, designed and the then fabricated, usually in china). And how much it costs/why. Resistors
cost 1/100 of a penny, jacks cost 50 cents, custom circuit
boards cost 50 cents (depending) Supra's main processor
(rp2350 which is cheap, new, and fastish) costs $1 - which, weirdly, is the same price as a single knob cap (?) (so you might be paying $5 in costs for knob caps on a synth and $1 for the processor) cheap faceplates cost $1 (circuit boards in disguise) expensive ones can be 20 times that. But, two years of support for someone to comfortable develop a module at 'market rate' in the US, ~$140,000, plus the cost for whoever assembles and distributes it. When you buy a module, you pay something for materials and assembly, but you're mostly paying for intellectual property - for technical skills, design, ideas.

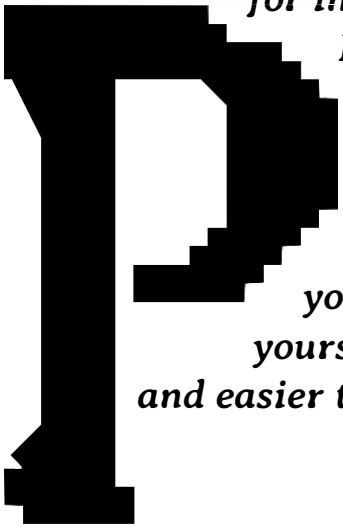
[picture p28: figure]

Knowing that can demonstrate to consumers that if they have design files (open source) and a little money or a group of people, they can have real affordability. Ordering circuit boards is 1000 times easier than designing a module - anyone can learn how to do it. If you can source the intellectual labor free (or make them yourself) bringing them into the physical world is cheaper and easier than you'd think.

(Note that intellectual labor is given for free all the time in the open source software world, and creative hardware can and should be the same, but we need to work on further normalizing and contributing to it.)

So, 2 expectations of makers

- publicize your costs
- when a module is discontinued, open source the design and manufacturing files. (ideally make a
small post actually showing people how to order everything)

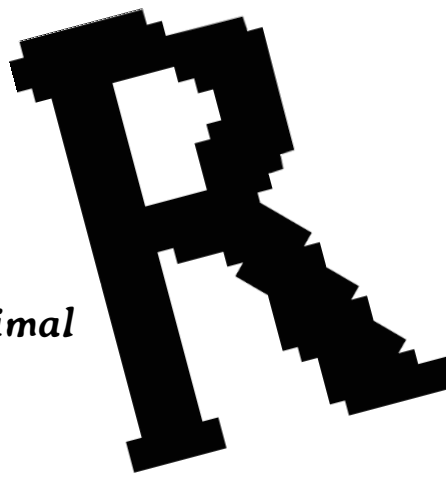
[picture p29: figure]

^neither of these cost money, and require pretty minimal effort

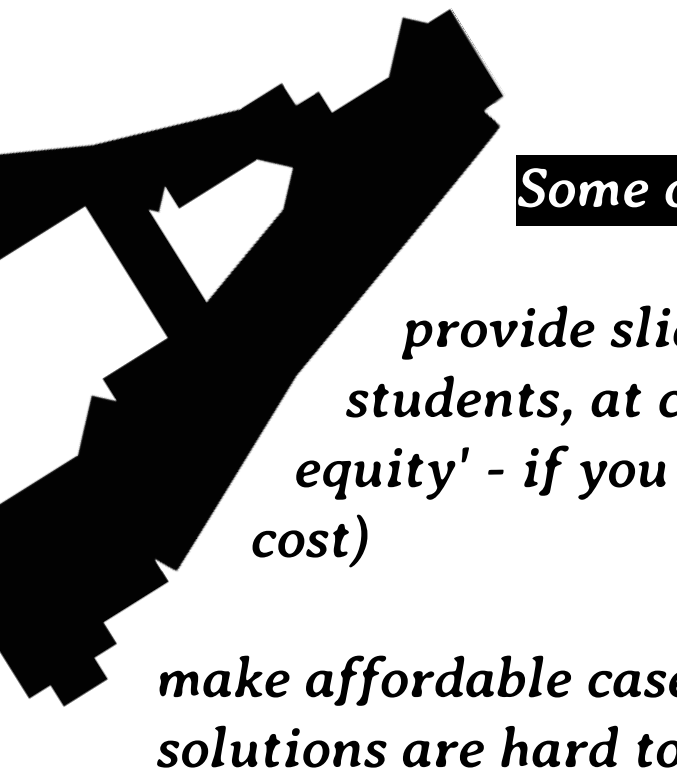
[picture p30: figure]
cost)

Some other things makers can do

provide sliding scale prices for modules, or at-cost for students, at cost for github contributors etc. (aka 'sweat equity' - if you contribute something to the project you pay at-

make affordable cases - cases are a barrier to entry and cheap solutions are hard to come by - its a box that converts voltage with some crew holes, it doesn't need to cost much to make or sell ^similarly with power supply modules

make affordable audio/cv interfaces
- very key for people with limited eurorack gear. Very little is out there for this beyond Expert Sleepers - 4 channel audio/cv interface can be easily made for wayyy cheaper than you can find right now

# Acknowledgments

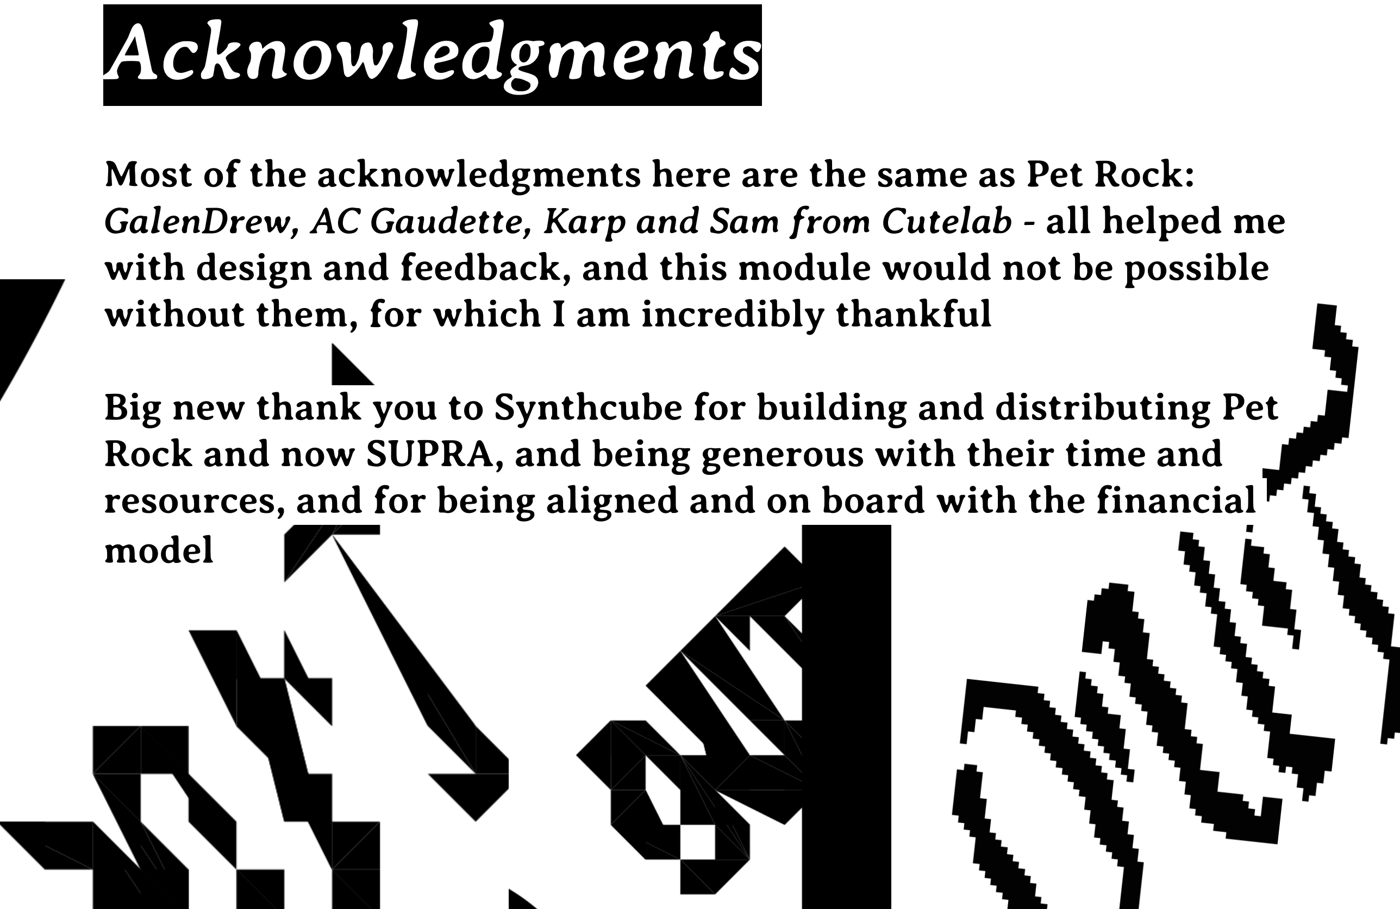
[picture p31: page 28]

Most of the acknowledgments here are the same as Pet Rock: GalenDrew, AC Gaudette, Karp and Sam from Cutelab - all helped me with design and feedback, and this module would not be possible without them, for which I am incredibly thankful

Big new thank you to Synthcube for building and distributing Pet Rock and now SUPRA, and being generous with their time and resources, and for being aligned and on board with the financial model

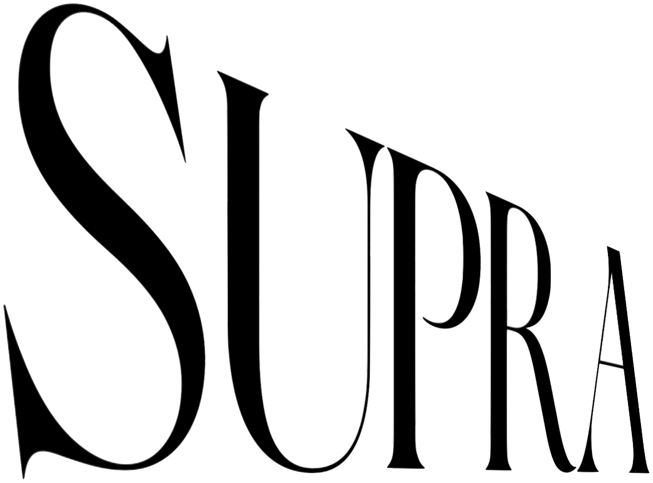
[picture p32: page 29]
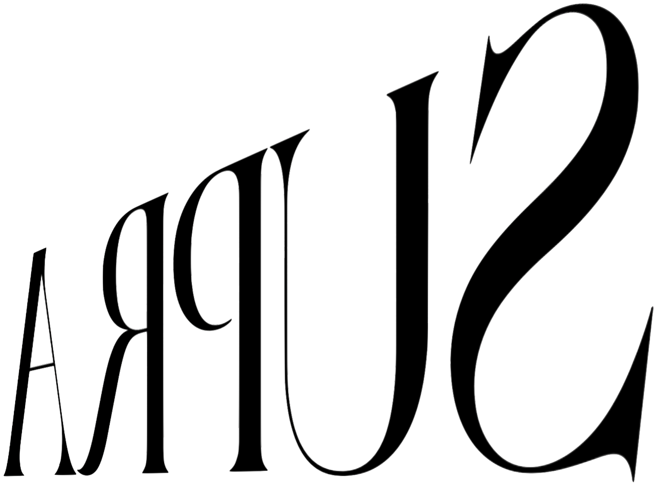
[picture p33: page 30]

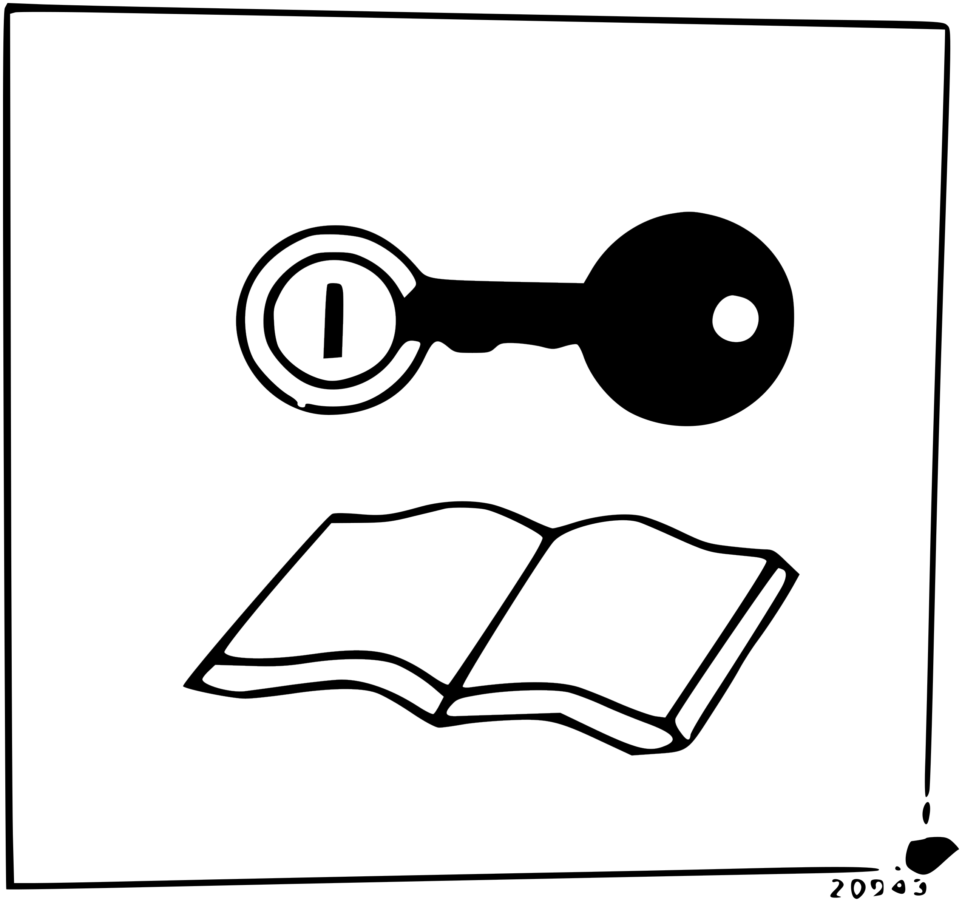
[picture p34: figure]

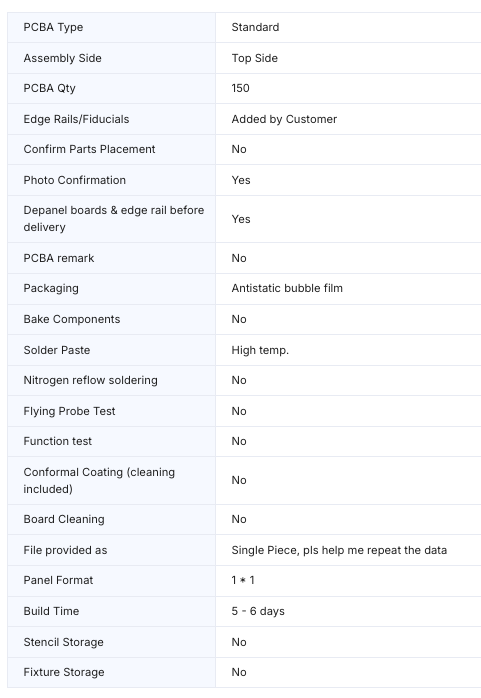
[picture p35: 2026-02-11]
hardware/JLCPCB fabrication files/SUPRA ASSEMBLY OPTIONS.png

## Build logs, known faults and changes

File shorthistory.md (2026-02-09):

  <h1 style="font-family: Baskerville" source align="center">
  A Short History of SUPRA
  </h1>

<p align="center">
first prototype

  <p style="font-family: Baskerville" source align="center">
  this is the very first supra prototype: a raspberry pi pico, a display, a joystick, and 2 jacks on a piece of 50 cent perfboard. This lasted a long while. I spent the first couple weeks of work on supra obsessing and slaving over getting the u8g2 library to work in c++ instead of c. I was convinced that some small extra setup steps to using the C library each time would prove to be massively annoying. I think this was driven by feeling like I could have done things better with some earlier on setup of tools/code pipeline on my previous module Pet Rock. It ended up being a crazy wild goose chase. I spent so much time on it, then just opened a github issue where the dev said, no that's not supported, and then I used the C version anyway. It was totally fine, wasted a lot of time thinking I needed to do something the "right way"
  </p>

<br/>
<br/>
<br/>

<p align="center">
first proto screen

  <p source align="center">
    This is a super early version of cryptex. I spent a loooot of time debugging off by 1 errors etc. I would do things myself, get it wrong, feed it to some llm,
    which would try somewhat convincingly, and inevitable fail miserably, then go back to debugging myself etc. The whole 'play head' model of clock coming in and then 
    determining where to go and when to wait for how long based on each letter and each word was deceptively challenging
  </p>

<br/>
<br/>
<br/>

<p align="center">
2nd proto
2nd proto 2

  <p source align="center">
    This is the second prototype. Similar but with better perf board, and a real time clock. These are the first versions of abacus and stamp. Tried to get the 2nd pico working as a debugger, failed constantly lol, but I guess i figured it out with a lot of trial and error and no runtime error message ability
  </p>

<br/>
<br/>
<br/>

<p align="center">
notebook

  <p source align="center">
   some imaginings of the front panel. Most of my designs of supra included another meta layer of use which would involve modifying the modes over time, or aquiring new ones
    this one is my phase of having a "shop" where you would accumulate points while using the module and spend them on mutations and upgrades of the mode. I still
    am really enamored with this idea, but It didn't end up fitting in very well. I could never nail down exactly what you would buy etc. I feel like if I had put
    in more work I could have figured it out, and I still want to make something like that sometime. Another huge idea was having an overworld with a character that 
    would move around and do things - there was going to be a pirate trader ship that each sunday would bring new modes that you could swap with ones in your inventory
    to use for a while. This meta trading system was really based on the idea that there would be 10+ modes, and that they would be simpler and more combinatorial. With 
    the 4 I ended up with it just didn't make sense. Cutting that was the hardest thing in development, because it was one of the things I was most excited by. I think 
    now after having to explain the 4 modes to everyone as they confusidly ponder supra, that it would have been incredibly difficult to 
    explain such an incredibly complex module to people. But I don't really make things to be easily understandable, I want them to be different and deep and experimental. 
    so that is still my greatest dissapointment with supra, that I missed that extra level of depth and complexity. But that's been a legitimate point of learning about
    how I scope and design. Pet Rock was so straight forward: I had to make design decisions, but not many. I was mostly executing on my original vision. Supra was so much 
    more open ended, its helped me see how I would change my design methodology in the future. I'm still very proud of the module and how things came out, and I have so much 
    fun using it myself, which is really the thing that matters most to me. 
  </p>

<br/>
<br/>
<br/>

<p align="center">

 <p source align="center">
   
   another side project of the project that never made it was resin 3d printing the topper for the joystick. I was going to do a bunch of crazy and interesting shapes. Resin 3d printing is an incredible technology and allows you to print one off parts in super high precision to the point where they look industrially made. But they are brittle, etc. etc. The foray i did was fun but I started to realize that getting it right was going to be a major endeavor and take way too much work for something that would be an "oh neat" moment, not a core functionality of the device 
   
 </p>
<br/>
<br/>
<br/>

<p align="center">
logos1
logos2
  
  <p align="center">
LR

  <p source align="center">
  These were some hand drawn logo ideas, which was really fun. It's so easy for me to get lost in graphic design and visual things, because they're so far from everything
    I usually work on. They really feel like a guilty pleasure, I can do whatever I want and it feels so free because I don't think of myself as a graphic designer
    or a visuals person. I just follow the feel of things
  </p>

<br/>
<br/>
<br/>

<p align="center">
render

  <p source align="center">
  This was the first render of my first panel design, which remained essentially unchanged. I do panel design in a tiny stint, an hour or two. I like the absolute chaos
    of that flow state. I like that my panels look completely trashed out. Everything is completely unaligned. My room looks exactly like my panels. Probably messier actually
  </p>

<br/>
<br/>
<br/>

<p align="center">
Screenshot 2026-02-09 at 4 49 46 PM

  <p source align="center">
 I planned to go to superbooth for a long time. I found the only way I actually finished Pet Rock was by setting a date to exhibit it (at knobcon) so I did the same. 
    turned out this time it took another 9 months of random delays, some my fault, some not. That has been very frustrating because mentally I was going to be done with the
    project nine months before writing this, and everything stretched out crazily. Superbooth itself was a mad dash to finish. I had a package of circuit boards come in so 
    close that i redirected it to berlin, and I had no soldering equipment to assemble them. I couldn't find one hackerspace open that would allow me to use any tools. So 
    I ended up soldering everything on the balcony of my friend I was staying with with the cheapest possible tools from a hardware store. It was a beautiful day. At one point
    a bag of extremely tiny hard to get lightpipes blew off the balcony and I rand down to the street barefoot to try and find them. A nice shop owner helped me spy them on top of an awning and get them down. I had finished the code during an insane fever dream of jet lag at a berlin library before taking a nap in a park
  </p>

<br/>
<br/>

<p align="center">
sbsign
sbtable

  <p source align="center">
    Superbooth itself was fun, and exhausting. Doing 9 hour days of standing in a room full of 12 types of simultaneous unsynced acid techno was a little brutal. I started walking around for my sanity a bit more after day 2. This may sound stupid but there were SO MANY SYNTHESIZERS. It made me feel a little crazy hahaha. On the other side the live music was by far the best I've ever seen at an event like that, and the grounds were amazing
  </p>

  <h1 source align="center">
That's all!  </h1>

<p source align="center">
it's hard to be launching what feels like so late. What keeps me sane is seeing other makers struggle in the same ways. Parts go out of stock, 2 more weeks. Parts go out of stock again, 2 more weeks. Endless to do lists of busy and technical work that's totally apart from any job or organizational system. The fun part is completely over, and then you have to force yourself to do pure logistics until its out!!! so I'm chalking it up to another learning experience. And there's only been a few moments of agony lol. I've actually had soooooo much fun making supra. It's been a true true labor of love :) I hope it brings a little joy to someone else too </p>
</p>

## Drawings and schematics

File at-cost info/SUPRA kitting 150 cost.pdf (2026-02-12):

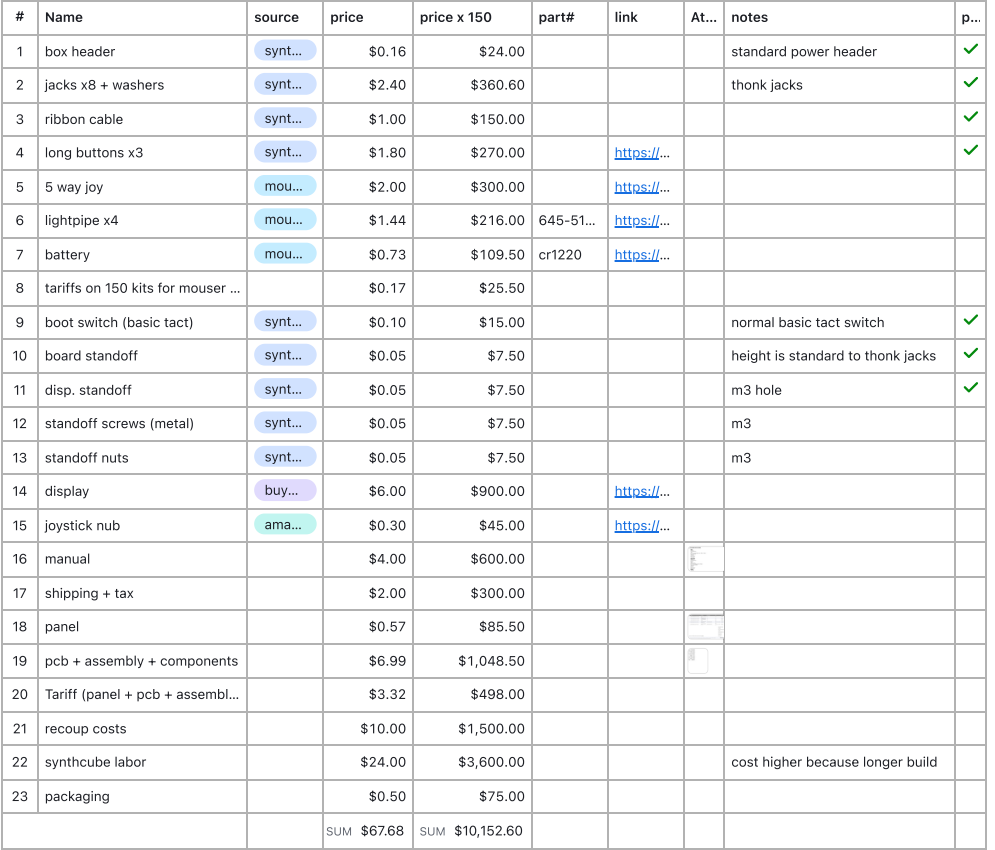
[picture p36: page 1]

# | Name | source | price | price x 150 | part# | link | At… | notes | p…

1 | box header | synt… | $0.16 | $24.00 | | | | standard power header

2 | jacks x8 + washers | synt… | $2.40 | $360.60 | | | | thonk jacks

3 | ribbon cable | synt… | $1.00 | $150.00

4 | long buttons x3 | synt… | $1.80 | $270.00 | | https://… (https://www.mouser.com/ProductDetail/612-1105SPF160Q1RWHT)

5 | 5 way joy | mou… | $2.00 | $300.00 | | https://… (https://www.adafruit.com/product/504)

6 | lightpipe x4 | mou… | $1.44 | $216.00 | 645-51… | https://… (https://www.mouser.com/ProductDetail/645-515-1303-0300F)

7 | battery | mou… | $0.73 | $109.50 | cr1220 | https://… (https://www.mouser.com/ProductDetail/658-CR1220)

8 | tariffs on 150 kits for mouser … | | $0.17 | $25.50

9 | boot switch (basic tact) | synt… | $0.10 | $15.00 | | | | normal basic tact switch

10 | board standoff | synt… | $0.05 | $7.50 | | | | height is standard to thonk jacks

11 | disp. standoff | synt… | $0.05 | $7.50 | | | | m3 hole

12 | standoff screws (metal) | synt… | $0.05 | $7.50 | | | | m3

13 | standoff nuts | synt… | $0.05 | $7.50 | | | | m3

14 | display | buy… | $6.00 | $900.00 | | https://… (https://www.buydisplay.com/i2c-white-1-3-inch-oled-display-module-128x64-arduino-raspberry-pi)

15 | joystick nub | ama… | $0.30 | $45.00 | | https://… (https://www.amazon.com/dp/B07PGTZP9Z?ref_=ppx_hzsearch_conn_dt_b_fed_asin_title_2)

16 | manual | | $4.00 | $600.00

17 | shipping + tax | | $2.00 | $300.00

18 | panel | | $0.57 | $85.50

19 | pcb + assembly + components | | $6.99 | $1,048.50

20 | Tariff (panel + pcb + assembl… | | $3.32 | $498.00

21 | recoup costs | | $10.00 | $1,500.00

22 | synthcube labor | | $24.00 | $3,600.00 | | | | cost higher because longer build

23 | packaging | | $0.50 | $75.00

SUM $67.68 | SUM $10,152.60

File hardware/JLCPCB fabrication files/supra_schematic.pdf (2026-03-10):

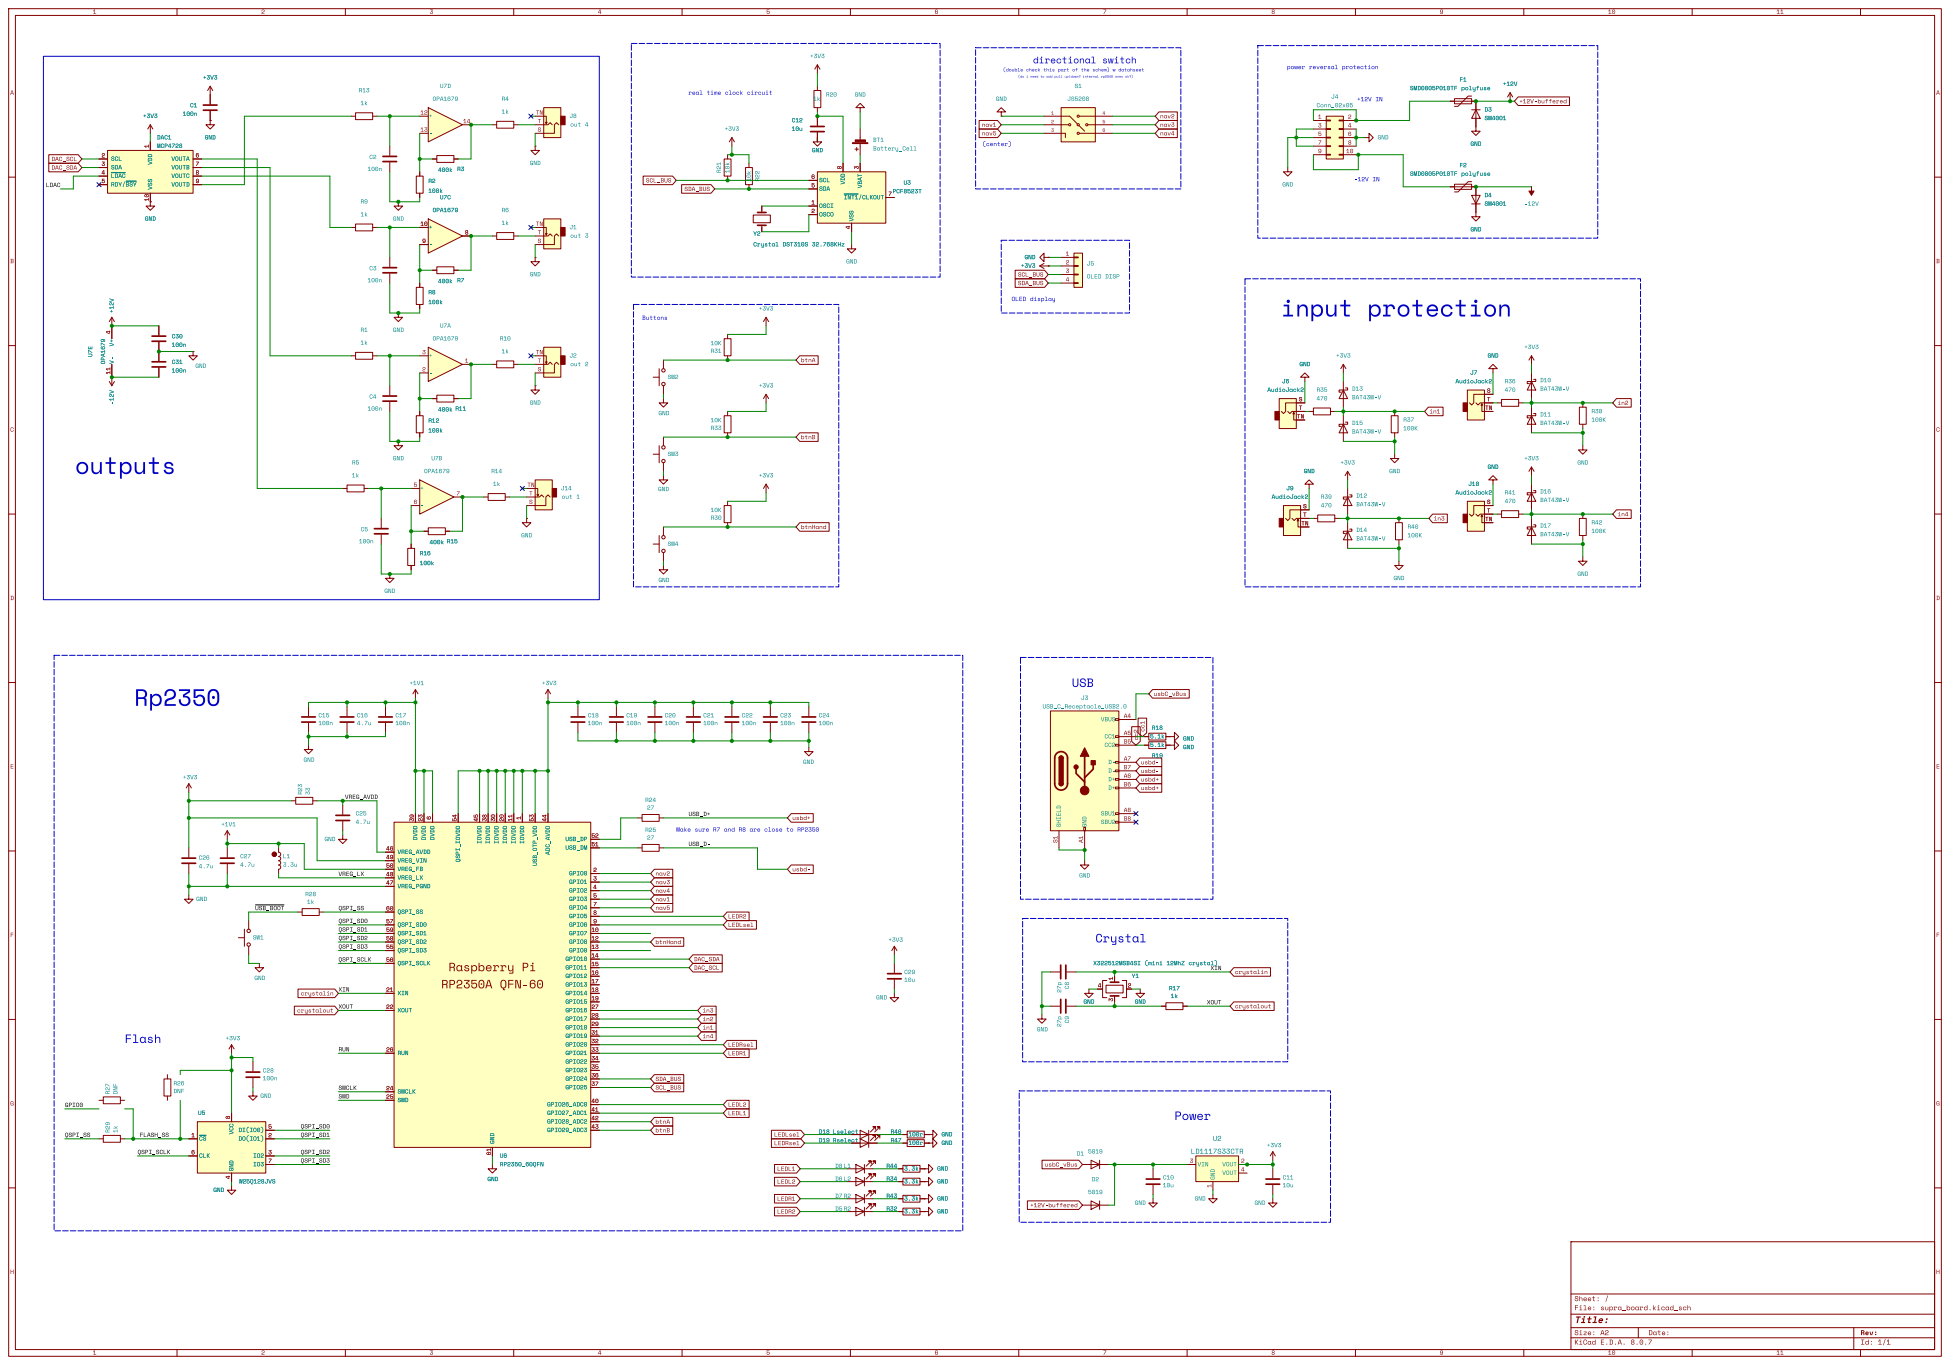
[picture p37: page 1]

Make sure R7 and R8 are close to RP2350

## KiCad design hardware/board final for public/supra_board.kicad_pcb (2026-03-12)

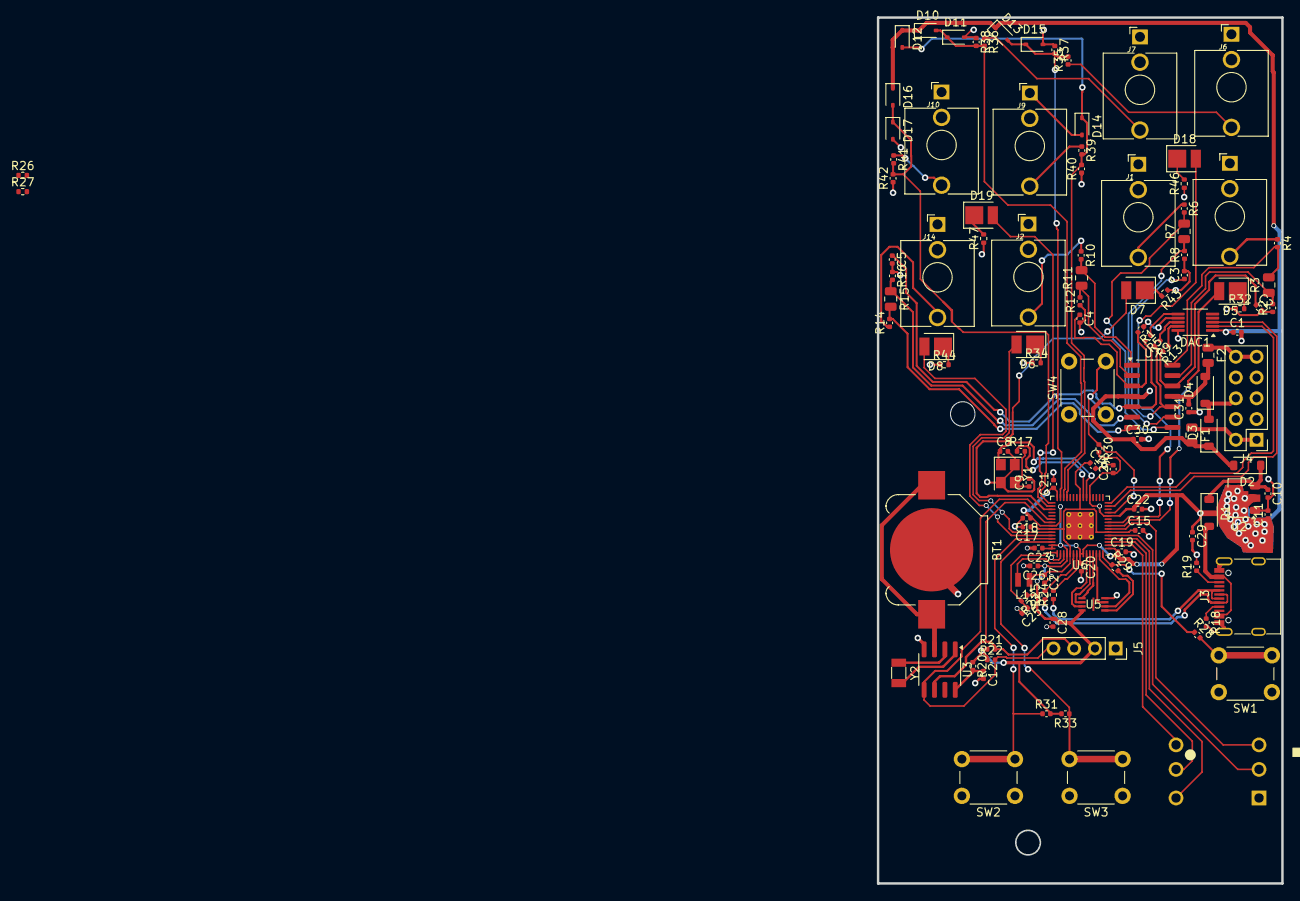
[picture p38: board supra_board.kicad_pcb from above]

Board: 2 copper layers, 49.5 x 106.0 mm, 119 parts (1 on the bottom side), 84 nets.

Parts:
BT1: Battery_Cell; BatteryHolder_Keystone_3000_1x12mm
C1, C2, C3, C4, C5, C15, C17, C18, C19, C20, C21, C22, C23, C24, C28, C30, C31: 100n; C_0402_1005Metric
C8, C9: 27p; C_0402_1005Metric
C10, C11, C12, C29: 10u; C_0402_1005Metric
C16, C25, C26, C27: 4.7u; C_0402_1005Metric
D1, D2: 5819; D_SOD-123
D3, D4: SM4001; D_SOD-123
D5, D7: R2; LED_PLCC_2835
D6: L2; LED_PLCC_2835
D8: L1; LED_PLCC_2835
D10, D11, D12, D13, D14, D15, D16, D17: BAT43W-V; D_SOD-323
D18: Lselect; LED_PLCC_2835
D19: Rselect; LED_PLCC_2835
DAC1: MCP4728; MSOP-10_3x3mm_P0.5mm
F1, F2: SMD0805P010TF polyfuse; Fuse_0805_2012Metric
J1: out 3; _Jack_3.5mm_QingPu_JACK_ANCHOR
J2: out 2; _Jack_3.5mm_QingPu_JACK_ANCHOR
J3: USB_C_Receptacle_USB2.0; USB_C_Receptacle_G-Switch_GT-USB-7010ASV
J4: Conn_02x05; PinHeader_2x05_P2.54mm_Vertical
J5: OLED DISP; PinSocket_1x04_P2.54mm_Vertical
J6, J7, J9, J10: AudioJack2; _Jack_3.5mm_QingPu_JACK_ANCHOR
J8: out 4; _Jack_3.5mm_QingPu_JACK_ANCHOR
J14: out 1; _Jack_3.5mm_QingPu_JACK_ANCHOR
L1: 3.3u; L_pol_2016
R1, R4, R5, R6, R9, R10, R13, R14, R17, R20, R28: 1k; C_0402_1005Metric
R2, R8, R12, R16: 100k; C_0402_1005Metric
R3, R7, R11, R15: 400k; C_0805_2012Metric
R18, R19: 5.1k; C_0402_1005Metric
R21, R22: 10k; C_0402_1005Metric
R23: 33; R_0402_1005Metric
R24, R25: 27; R_0402_1005Metric
R26, R27: DNF; R_0402_1005Metric
R29: 1k; R_0402_1005Metric
R30, R31, R33: 10K; C_0402_1005Metric
R32, R34, R43, R44: 3.3k; R_0402_1005Metric
R35, R36, R39, R41: 470; C_0402_1005Metric
R37, R38, R40, R42: 100K; C_0402_1005Metric
R46, R47: 100r; R_0402_1005Metric
S1: JS5208; sw_nav_5waySUPRA
SW1: btnBOOT; SW_PUSH_6mm
SW2: btnA; SW_PUSH_6mm
SW3: btnB; SW_PUSH_6mm
SW4: btnHand; SW_PUSH_6mm
U2: LD1117S33CTR; SOT-89-3
U3: PCF8523T; SOIC-8_3.9x4.9mm_P1.27mm
U5: W25Q128JVS; SON50P300X200X60-9N
U6: RP2350_60QFN; RP2350-QFN-60-1EP_7x7_P0.4mm_EP3.4x3.4mm_ThermalVias
U7: OPA1679; SOIC-14_3.9x8.7mm_P1.27mm
Y1: X322512MSB4SI (mini 12MhZ crystal); Crystal_SMD_3225-4Pin_3.2x2.5mm
Y2: Crystal DST310S 32.768KHz; Crystal_SMD_3215-2Pin_3.2x1.5mm

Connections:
+1V1: C15.1, C16.1, C17.1, C27.1, L1.1, U6.6 (DVDD), U6.23 (DVDD), U6.39 (DVDD), U6.50 (VREG_FB)
+3V3: C1.1, C11.1, C18.1, C19.1, C20.1, C21.1, C22.1, C23.1, C24.1, C26.1, C28.1, C29.1, D10.1 (K), D12.1 (K), D13.1 (K), D16.1 (K), DAC1.1 (VDD), J5.2, R20.1, R21.1, R22.1, R23.1, R30.2, R31.2, R33.2, U2.2 (VOUT), U5.8 (VCC), U6.1 (IOVDD), U6.11 (IOVDD), U6.20 (IOVDD), U6.30 (IOVDD), U6.38 (IOVDD), U6.44 (ADC_AVDD), U6.45 (IOVDD), U6.49 (VREG_VIN), U6.53 (USB_OTP_VDD), U6.54 (QSPI_IOVDD)
+12V-buffered: C30.1, D2.2 (A), D3.1 (K), F1.2, U7.4 (V+)
-12V: C31.2, D4.2 (A), F2.2, U7.11 (V-)
/FLASH_SS: R29.2, U5.1 (~CS)
/QSPI_SCLK: U5.6 (CLK), U6.56 (QSPI_SCLK)
/QSPI_SD0: U5.5 (DI(IO0)), U6.57 (QSPI_SD0)
/QSPI_SD1: U5.2 (DO(IO1)), U6.59 (QSPI_SD1)
/QSPI_SD2: U5.3 (IO2), U6.58 (QSPI_SD2)
/QSPI_SD3: U5.7 (IO3), U6.55 (QSPI_SD3)
/QSPI_SS: R28.1, R29.1, U6.60 (QSPI_SS)
/VREG_AVDD: C25.1, R23.2, U6.46 (VREG_AVDD)
/VREG_LX: L1.2, U6.48 (VREG_LX)
/~USB_BOOT: R28.2, SW1.2
DAC_SCL: DAC1.2 (SCL), U6.15 (GPIO11)
DAC_SDA: DAC1.3 (SDA), U6.14 (GPIO10)
GND: BT1.2 (-), C1.2, C2.2, C3.2, C4.2, C5.2, C8.2, C9.2, C10.2, C11.2, C12.2, C15.2, C16.2, C17.2, C18.2, C19.2, C20.2, C21.2, C22.2, C23.2, C24.2, C25.2, C26.2, C27.2, C28.2, C29.2, C30.2, C31.1, D3.2 (A), D4.1 (K), D11.2 (A), D14.2 (A), D15.2 (A), D17.2 (A), DAC1.10 (VSS), J1.S, J2.S, J3.A1 (GND), J3.A12 (GND), J3.B1 (GND), J3.B12 (GND), J3.S1 (SHIELD), J4.3, J4.4, J4.5, J4.6, J4.7, J4.8, J5.1, J6.S, J7.S, J8.S, J9.S, J10.S, J14.S, R2.1, R8.1, R12.1, R16.1, R18.2, R19.2, R32.1, R34.1, R37.1, R38.1, R40.1, R42.1, R43.1, R44.1, R46.1, R47.1, S1.1, SW1.1, SW2.1, SW3.1, SW4.1, U2.1 (GND), U3.4 (VSS), U5.4 (GND), U6.47 (VREG_PGND), U6.61 (GND), Y1.2, Y1.4
LEDL1: D8.2 (A), U6.41 (GPIO27_ADC1)
LEDL2: D6.2 (A), U6.40 (GPIO26_ADC0)
LEDLsel: D18.2 (A), U6.9 (GPIO6)
LEDR1: D7.2 (A), U6.33 (GPIO21)
LEDR2: D5.2 (A), U6.8 (GPIO5)
LEDRsel: D19.2 (A), U6.32 (GPIO20)
unnamed: BT1.1 (+), U3.3 (VBAT)
unnamed: C9.1, R17.2, Y1.3
unnamed: C10.1, D1.1 (K), D2.1 (K), U2.3 (VIN)
unnamed: D5.1 (K), R32.2
unnamed: D6.1 (K), R34.2
unnamed: D7.1 (K), R43.2
unnamed: D8.1 (K), R44.2
unnamed: D18.1 (K), R46.2
unnamed: D19.1 (K), R47.2
unnamed: DAC1.6 (VOUTA), R5.1
unnamed: DAC1.7 (VOUTB), R1.1
unnamed: DAC1.8 (VOUTC), R9.1
unnamed: DAC1.9 (VOUTD), R13.1
unnamed: J1.T, R6.1
unnamed: J2.T, R10.1
unnamed: F1.1, J4.1, J4.2
unnamed: F2.1, J4.9, J4.10
unnamed: J6.T, R35.1
unnamed: J7.T, R36.1
unnamed: J8.T, R4.1
unnamed: J9.T, R39.1
unnamed: J10.T, R41.1
unnamed: J14.T, R14.1
unnamed: R3.2, R4.2, U7.14
unnamed: R6.2, R7.2, U7.8
unnamed: R10.2, R11.2, U7.1
unnamed: R14.2, R15.2, U7.7
unnamed: U3.1 (OSCI), Y2.1
unnamed: U3.2 (OSCO), Y2.2
unnamed: C12.1, R20.2, U3.8 (VDD)
unnamed: R25.2, U6.51 (USB_DM)
unnamed: R24.2, U6.52 (USB_DP)
unnamed: C4.1, R1.2, U7.3 (+)
unnamed: R11.1, R12.2, U7.2 (-)
unnamed: C5.1, R5.2, U7.5 (+)
unnamed: R15.1, R16.2, U7.6 (-)
unnamed: C3.1, R9.2, U7.10 (+)
unnamed: R7.1, R8.2, U7.9 (-)
unnamed: C2.1, R13.2, U7.12 (+)
unnamed: R2.2, R3.1, U7.13 (-)
SCL_BUS: J5.3, R21.2, U3.6 (SCL), U6.37 (GPIO25)
SDA_BUS: J5.4, R22.2, U3.5 (SDA), U6.36 (GPIO24)
btnA: R31.1, SW2.2, U6.42 (GPIO28_ADC2)
btnB: R33.1, SW3.2, U6.43 (GPIO29_ADC3)
btnHand: R30.1, SW4.2, U6.12 (GPIO8)
cc1: J3.A5 (CC1), R18.1
cc2: J3.B5 (CC2), R19.1
crystalin: C8.1, U6.21 (XIN), Y1.1
crystalout: R17.1, U6.22 (XOUT)
in1: D13.2 (A), D15.1 (K), R35.2, R37.2, U6.29 (GPIO18)
in2: D10.2 (A), D11.1 (K), R36.2, R38.2, U6.28 (GPIO17)
in3: D12.2 (A), D14.1 (K), R39.2, R40.2, U6.27 (GPIO16)
in4: D16.2 (A), D17.1 (K), R41.2, R42.2, U6.31 (GPIO19)
nav1: S1.2, U6.5 (GPIO3)
nav2: S1.4, U6.2 (GPIO0)
nav3: S1.5, U6.3 (GPIO1)
nav4: S1.6, U6.4 (GPIO2)
nav5: S1.3, U6.7 (GPIO4)
usbC_vBus: D1.2 (A), J3.A4 (VBUS), J3.A9 (VBUS), J3.B4 (VBUS), J3.B9 (VBUS)
usbd+: J3.A6 (D+), J3.B6 (D+), R24.1
usbd-: J3.A7 (D-), J3.B7 (D-), R25.1

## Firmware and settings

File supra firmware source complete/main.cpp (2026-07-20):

// main.cpp
#include <stdio.h>
#include "pico/stdlib.h"
#include "pico/multicore.h"
#include "hardware/timer.h"
#include "Clock.h"   
#include "Module.h"  
#include "Squigl.h"  
#include "Seqo.h"    
#include "Melo.h"    
#include "morsed.h"    
#include "Screen.h"  
#include "Controls.h"
#include "IO.h"
#include "menus.cpp"
#include "fs.h"
#include "reflash_flags.h"
#include "pico/stdio.h"
#include "pico_hal.h"
#include "stdinit.h"
#include "bitmaps.c"
#include "anims.cpp"

#include "tusb.h"

// Dev-only escape hatch: set to 1 (via CMake `SUPRA_BYPASS_DATE_SET=1`)
// to skip the date/time menu entirely during rapid reflashing.
#ifndef SUPRA_BYPASS_DATE_SET
#define SUPRA_BYPASS_DATE_SET 0
#endif

// Forward declarations of module classes
class Seqo;
class Morsed;

// Create module instances for each hand
// Left hand modules (hand ID 0)
Melo meloLeft(0);
Squigl squiglLeft(0);
Seqo seqoLeft(0);
Morsed morsedLeft(0);

// Right hand modules (hand ID 1)
Melo meloRight(1);
Squigl squiglRight(1);
Seqo seqoRight(1);
Morsed morsedRight(1);

// Pointers to active modules (only one per hand)
Module* leftModule = &morsedLeft;    
Module* rightModule = &squiglRight; 

// Shared state between cores
volatile bool running = true;
int lookHand = 0;  // 0 = left hand, 1 = right hand
int lh = 20;
int rh = 6;
int frameCounter = 0;

// Menu system variables
bool menuActive = false;
int menuSelection = 0;
const char* menuItems[] = {"Abacus", "Stamp", "Cryptex", "Chime"};
const int menuItemCount = 4;

// Button press state tracking
bool button0WasPressed = false;
uint64_t button0PressStartTime = 0;
const int LONG_PRESS_TIME = 350; // ms for long press detection
bool longPressActivated = false;

int lhHoldTemp=0;
int rhHoldTemp=0;
bool shouldWritePrefs=false;
bool shouldReadPrefs=true;
bool suppressPrefWrite=false;
int prefsHandToWrite=0;
int prefsValueToWrite=0;

// Core 1 entry point - handles high-frequency DAC updates
void core1_entry() {
    sleep_ms(100);
    while (running) {
        IO_selfClockEnabledByHand[0] = false;
        IO_selfClockEnabledByHand[1] = false;
        leftModule->runFast();
        rightModule->runFast();
    }
}

// Function to display menu using u8g2 library
void displayMenu() {
    u8g2_ClearBuffer(&u8g2);

    //u8g2_DrawBox(&u8g2,42,0,85,64);
    
    // Draw menu title
    u8g2_SetFont(&u8g2, u8g2_font_6x10_tf);
    u8g2_SetFontPosTop(&u8g2);

    int xoff=74*(1-lookHand);

    u8g2_SetDrawColor(&u8g2, 1);
    if(lookHand==0)
    {
        u8g2_DrawStr(&u8g2, xoff, 5, "L Hand:");
        u8g2_DrawXBM(&u8g2,1,1,53,62,lhbmp);
    } else {
        u8g2_DrawStr(&u8g2, 0, 5, "R Hand:");
        u8g2_DrawXBM(&u8g2,76,1,53,62,rhbmp);
    }
    
    // Draw menu items with selection indicator
    int yOffset = 20;
    int lineHeight = 10;
    
    for (int i = 0; i < menuItemCount; i++) {
        int y = yOffset + (i * lineHeight);
        
        // Highlight selected item
        if (i == menuSelection) {
            // Draw selection highlight (inverted box)
            u8g2_SetDrawColor(&u8g2, 1);
            u8g2_DrawBox(&u8g2, 0+xoff, y, 41, lineHeight);
            u8g2_SetDrawColor(&u8g2, 0);  // Set to inverse color for text
            
            // Draw selection arrow
            //u8g2_SetFont(&u8g2, u8g2_font_unifont_t_symbols);
            //u8g2_DrawGlyph(&u8g2, 10, y + 1, 9658);  // Right arrow symbol
        } else {
            u8g2_SetDrawColor(&u8g2, 1);  // Normal color for text
        }
        
        // Draw menu item text
        u8g2_SetFont(&u8g2, u8g2_font_6x10_tf);
        u8g2_DrawStr(&u8g2, 0+xoff, y, menuItems[i]);
        
        // Reset draw color to normal
        u8g2_SetDrawColor(&u8g2, 1);
    }
    
    // Update the display
    u8g2_UpdateDisplay(&u8g2);
}

void applyModuleSelection() {
    //selectAnim();
    // Get current hand module pointer

    
    Module** currentHandModule = (lookHand == 0) ? &leftModule : &rightModule;

    if (menuSelection < 0) {
        menuSelection = 0;
    } else if (menuSelection >= menuItemCount) {
        menuSelection = 0;
    }
    
    // Determine which module to activate based on the current hand and menu selection
    if (lookHand == 0) {  // Left hand

        switch (menuSelection) {
            case 0: // Seqo
                *currentHandModule = &seqoLeft;
                break;
                
            case 1: // Squigl
                *currentHandModule = &squiglLeft;
                break;
                
            case 2: // Morsed
                *currentHandModule = &morsedLeft;
                break;
                
            case 3: // Melo
                *currentHandModule = &meloLeft;
                break;
        }

    } else {  // Right hand
        gpio_put(21,0);
        gpio_put(5,0);
        switch (menuSelection) {
            case 0: // Seqo
                *currentHandModule = &seqoRight;
                break;
                
            case 1: // Squigl
                *currentHandModule = &squiglRight;
                break;
                
            case 2: // Morsed
                *currentHandModule = &morsedRight;
                break;
                
            case 3: // Melo
                *currentHandModule = &meloRight;
                break;
        }
    }

   
    
    // Always reinitialize the module when selected from the menu
    // This ensures all internal state is properly reset
    printf("Changed module for %s hand to %s - reinitializing...\n", 
           lookHand == 0 ? "left" : "right", 
           menuItems[menuSelection]);
    
    // Reinitialize the new module
    (*currentHandModule)->initialize();
    
    // Auto-close the menu when a selection is made
    menuActive = false;
  
    if(lookHand==0)
    {
        lhHoldTemp=menuSelection;
    } 

    if(lookHand==1)
    {
        rhHoldTemp=menuSelection;
    } 

    if (!suppressPrefWrite) {
        prefsHandToWrite = lookHand;
        prefsValueToWrite = menuSelection;
        shouldWritePrefs = true;
    }

    gpio_put(27,0);
    gpio_put(26,0);
    gpio_put(21,0);
    gpio_put(5,0);

   
}

// Main function runs on core 0
int main() {
    // Initialize stdio for debugging
    stdio_init_all();

    u8g2_ClearBuffer(&u8g2);
    display_sequence();

    //u8g2_SetFont(&u8g2, u8g2_font_logisoso42_tf);
    u8g2_SetFont(&u8g2, u8g2_font_logisoso26_tf);
    u8g2_SetFontMode(&u8g2, 1);
    int start=12;
    int spacing=random(17,22);
    int y=48;
    int rl=30;
    int ru=60;
    int rx=0;
    int ry=0;
    int delay=12;

    //y=random(rl,ru);
   
    u8g2_ClearBuffer(&u8g2);
    u8g2_DrawStr(&u8g2, start, y,"S");
    sleep_ms(delay);
    u8g2_UpdateDisplay(&u8g2);

    u8g2_ClearBuffer(&u8g2);
    u8g2_DrawStr(&u8g2, start+(spacing), y,"U");
    sleep_ms(delay);
    u8g2_UpdateDisplay(&u8g2);

    u8g2_ClearBuffer(&u8g2);
    u8g2_DrawStr(&u8g2, start+(spacing*2), y,"P");
    sleep_ms(delay);
    u8g2_UpdateDisplay(&u8g2);

    u8g2_ClearBuffer(&u8g2);
    u8g2_DrawStr(&u8g2, start+(spacing*3), y,"R");
    sleep_ms(delay);
    u8g2_UpdateDisplay(&u8g2);

    u8g2_ClearBuffer(&u8g2);
    u8g2_DrawStr(&u8g2, start+(spacing*4), y,"A");
    sleep_ms(delay);
    u8g2_UpdateDisplay(&u8g2);
    
    int rxl=10; 
    int rxh=80; 

    int ryl=30; 
    int ryh=50; 

    //sleep_ms(1000);
    
    con_init();  

    //while (!tud_cdc_connected()) { sleep_ms(100);}

    printf("con init done\n");
                              
    if (pico_mount(false) != LFS_ERR_OK) {
        printf("Error mounting FS AT MENU\n");
        pico_mount(true);
        //runDateMenu();
    }

    printf("pico mount done\n");
    
    if (!SUPRA_BYPASS_DATE_SET) {
        if(!supra_reflash_date_is_set())
        {
            runDateMenu();
            supra_reflash_date_mark_set();
        }
    }
    

    /*
    menuSelection=fs_readInt("prefs_lhHold");
    printf("menu selectL: %d\n",menuSelection);

    Module** currentHandModule = &leftModule;

    switch(menuSelection)
    {
        case 0:
            *currentHandModule=&seqoLeft;
        case 1:
            *currentHandModule=&squiglLeft;
        case 2:
            *currentHandModule=&morsedLeft;
        case 3:
            *currentHandModule=&meloLeft;
    }
    */

    /*
    menuSelection=fs_readInt("prefs_rhHold");
    printf("menu selectR: %d\n",menuSelection);
    applyModuleSelection();
    */

    //selectAnim();

    lookHand=0;
    
    printf("fs write read done\n");
    printf("prefs load done\n");
    

    // Initialize system components
    if(clock_init()==1)
    {
        runDateMenu();
        clock_init();
    }

    clock_read();

    printf("clocks done\n");

    //srand(03032025);
    srand(daySeed);
    IO_init();

    //IO_write_pwm(26, IO_pwmWrap);  // should go full bright
    //IO_write_pwm(5,  IO_pwmWrap); 

    printf("IO done\n");
    
    // Initialize all modules for both hands
    meloLeft.initialize();
    printf("got past melo init\n");
    squiglLeft.initialize();
    printf("got past squig init\n");
    seqoLeft.initialize();
    printf("got past seqo init\n");
    morsedLeft.initialize();
    printf("got past morsed init\n");
    
    meloRight.initialize();
    squiglRight.initialize();
    seqoRight.initialize();
    morsedRight.initialize();

    // Configure GPIOs
    
    gpio_init(lh);
    gpio_set_dir(lh, GPIO_OUT);
    gpio_init(rh);
    gpio_set_dir(rh, GPIO_OUT);

    printf("got to post gpios");

    gpio_put(lh, 1);
    
    
    // Launch core 1 with our entry point
    printf("Starting core 1 for high-frequency DAC updates...\n");
    multicore_launch_core1(core1_entry);
    
    // Main loop on core 0 - handles UI, control, and display
    while (true) {
        if(shouldReadPrefs)
        {
            multicore_reset_core1();  //needed
                                      //
            suppressPrefWrite = true;

            menuSelection=fs_readInt("prefs_lhHold");
            if (menuSelection < 0 || menuSelection >= menuItemCount) {
                menuSelection = 0;
            }
            printf("menu selectL: %d\n",menuSelection);
            lookHand=0;
            applyModuleSelection();

            menuSelection=fs_readInt("prefs_rhHold");
            if (menuSelection < 0 || menuSelection >= menuItemCount) {
                menuSelection = 0;
            }
            printf("menu selectR: %d\n",menuSelection);
            lookHand=1;
            applyModuleSelection();

            lookHand=0;

            multicore_launch_core1(core1_entry);
            shouldReadPrefs=false;
            shouldWritePrefs=false;
            suppressPrefWrite = false;
        }    

        if(shouldWritePrefs)
        {
            multicore_reset_core1();  //needed
                                      
            if(prefsHandToWrite==0)
            {
                fs_writeInt("prefs_lhHold",prefsValueToWrite);

            } else {

                fs_writeInt("prefs_rhHold",prefsValueToWrite);
            }
            multicore_launch_core1(core1_entry);

            shouldWritePrefs=false;
  

            //sleep_ms(1);
        }

        // Current time for button press duration checking
        uint64_t currentTime = to_ms_since_boot(get_absolute_time());
        
        // Check button state - completely rewritten button handling logic
        bool button0IsPressed = button_contin(0);
        
        // State changes for button 0
        if (button0IsPressed && !button0WasPressed) {
            // Button just pressed
            button0PressStartTime = currentTime;
            longPressActivated = false;
        }
        
        // Handle long press detection and activation
        if (button0IsPressed && !longPressActivated && 
            (currentTime - button0PressStartTime >= LONG_PRESS_TIME)) {
            
            if (!menuActive) {
                // Only activate menu if it's not already active
                menuActive = true;
                
                // Set initial menu selection based on current module
                if (lookHand == 0) {
                    // Left hand
                    if (leftModule == &meloLeft) menuSelection = 3;
                    else if (leftModule == &seqoLeft) menuSelection = 0;
                    else if (leftModule == &squiglLeft) menuSelection = 1;
                    else if (leftModule == &morsedLeft) menuSelection = 2;
                    else menuSelection = 0; // Default
                } else {
                    // Right hand
                    if (rightModule == &squiglRight) menuSelection = 1;
                    else if (rightModule == &morsedRight) menuSelection = 2;
                    else if (rightModule == &meloRight) menuSelection = 3;
                    else if (rightModule == &seqoRight) menuSelection = 0;
                    else menuSelection = 0; // Default
                }
                
                displayMenu();
                printf("Menu activated for %s hand\n", lookHand == 0 ? "left" : "right");
            }
            
            longPressActivated = true; // Mark that we've processed this long press
        }
        
        // Handle short press detection
        if (!button0IsPressed && button0WasPressed) {
            // Button just released
            if (!longPressActivated && (currentTime - button0PressStartTime < LONG_PRESS_TIME)) {
                // This was a short press
                if (menuActive) {
                    // If menu is active, close it
                    menuActive = false;
                    printf("Menu deactivated\n");
                } else {
                    // Regular press behavior (switch lookHand)
                    if (lookHand == 1) {
                        lookHand = 0;
                        gpio_put(rh, 0);
                        gpio_put(lh, 1);
                        //swapAnim(0);
                        swapAnim(0);
                    } else if (lookHand == 0) {
                        lookHand = 1;
                        gpio_put(rh, 1);
                        gpio_put(lh, 0);
                        swapAnim(1);
                    }
                }
            }
        }
        
        // Save current button state for next loop
        button0WasPressed = button0IsPressed;

        IO_runPulse();
        
        if (menuActive) {
            // MENU MODE - handle joystick navigation
            int joyInput = con_joyMomentary();
            bool needRefresh = false;
            
            switch (joyInput) {
                case 1: // UP
                    if (menuSelection > 0) {
                        menuSelection--;
                        needRefresh = true;
                    }
                    break;
                    
                case 2: // DOWN
                    if (menuSelection < menuItemCount - 1) {
                        menuSelection++;
                        needRefresh = true;
                    }
                    break;
                    
                case 5: // CENTER (select)
                    // Select the current menu item, apply it and close menu
                    //
                    selectAnim();
                    applyModuleSelection();
                    break;
            }
            
            if (menuActive && (needRefresh || frameCounter % 5 == 0)) {
                displayMenu();
            }
        } else {
            // NORMAL MODE - run modules and update display
            
            // Run the slower logic portions of both active modules
            leftModule->run();
            rightModule->run();
            
            // Update display for the active module based on lookHand
            if (lookHand == 0) {
                leftModule->draw();
            } else {
                rightModule->draw();
            }
        }

        // Add a small delay to prevent core 0 from hogging resources
        // This doesn't affect core 1's timing for DAC updates
        sleep_ms(10);
        frameCounter++;
    }
    
    return 0;
}

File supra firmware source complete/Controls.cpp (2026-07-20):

#include <stdio.h>
#include "pico/stdlib.h"
#include "hardware/gpio.h"
#include "Controls.h"
#include "pico/time.h"

//int b0=28;
int b0=8;
int b1=28;
int b2=29;
//int b1=2;
//^real b1

bool b0Pressed;
bool b1Pressed;
bool b2Pressed;

//int inUp=11;
int inUp=0;
int inDown=2;
int inLeft=1;
int inRight=3;
//int inCenter=13;
int inCenter=4;

bool centerPressed=false;
bool upPressed=false;
bool downPressed=false;
bool leftPressed=false;
bool rightPressed=false;

#define INITIAL_DELAY 350 // ms before repeating starts
#define MIN_REPEAT_DELAY 20 // ms between repeats at max speed
#define ACCELERATION_RATE 0.65 // multiplier for decreasing delay

    void con_init()
    {

      //stdio_init_all();

      gpio_init(b0);
      gpio_init(b1);
      gpio_init(b2);

      gpio_init(inUp);
      gpio_init(inDown);
      gpio_init(inLeft);
      gpio_init(inRight);
      gpio_init(inCenter);

      gpio_set_function(inUp,GPIO_FUNC_SIO);

      gpio_pull_up(b0);
      gpio_pull_up(b1);
      gpio_pull_up(b2);

      gpio_pull_up(inUp);
      gpio_pull_up(inDown);
      gpio_pull_up(inLeft);
      gpio_pull_up(inRight);
      gpio_pull_up(inCenter);

      gpio_set_dir(b0,GPIO_IN);
      gpio_set_dir(b1,GPIO_IN);
      gpio_set_dir(b2,GPIO_IN);

      gpio_set_dir(inUp,GPIO_IN);
      gpio_set_dir(inDown,GPIO_IN);
      gpio_set_dir(inLeft,GPIO_IN);
      gpio_set_dir(inRight,GPIO_IN);
      gpio_set_dir(inCenter,GPIO_IN);

    }

    bool button_contin(int button)
    {
        //placeholder for testing, in the future button 2 will be different
        if(button==0)
        {
            if(gpio_get(b0)==0)
            {
                return true;
            } else {
                return false;
            }
        }

        if(button==1)
        {
            if(gpio_get(b1)==0)
            {
                return true;
            } else {
                return false;
            }
        }
        if(button==2)
        {
            if(gpio_get(b2)==0)
            {
                return true;
            } else {
                return false;
            }
        }
    }


    bool button_momentary(int button)
    {
       if(button==0)
       {
           if(gpio_get(b0)==0)
           {
                if(!b0Pressed)
                {
                    b0Pressed=true;
                    printf("b0 press\n");
                    return true;
                } else {
                    return false;
                }
           } else {
                b0Pressed=false;
                return false;
           }
       }

       if(button==1)
       {
           if(gpio_get(b1)==0)
           {
                if(!b1Pressed)
                {
                    b1Pressed=true;
                    printf("b1 press\n");
                    return true;
                } else {
                    return false;
                }
           } else {
                b1Pressed=false;
                return false;
           }
       }

       if(button==2)
       {
           if(gpio_get(b2)==0)
           {
                if(!b2Pressed)
                {
                    b2Pressed=true;
                    printf("b2 press\n");
                    return true;
                } else {
                    return false;
                }
           } else {
                b2Pressed=false;
                return false;
           }
       }
    }

    int con_joyMomentary()
    {

      //

      if(gpio_get(inUp)==0)
      {
          if(!upPressed)
          {
              printf("UP \n ");
              upPressed=true;
              return 1;
          }
      }

      if(gpio_get(inUp)==1)
      {
          upPressed=false;
      }

      //

      if(gpio_get(inDown)==0)
      {
          if(!downPressed)
          {
          printf("DOWN \n ");
          downPressed=true;
          return 2;
          }
      }

      if(gpio_get(inDown)==1)
      {
          downPressed=false;
      }

      //

      if(gpio_get(inLeft)==0)
      {
          if(!leftPressed)
          {
          printf("LEFT \n ");
          leftPressed=true;
          return 3;
          }
      }

      if(gpio_get(inLeft)==1)
      {
          leftPressed=false;
      }

      //

      if(gpio_get(inRight)==0)
      {
          if(!rightPressed)
          {
          printf("RIGHT \n ");
          rightPressed=true;
          return 4;
          }
      }

      if(gpio_get(inRight)==1)
      {
          rightPressed=false;
      }

      //

      if(gpio_get(inCenter)==0)
      {
          if(!centerPressed)
          {
          printf("CENTER \n ");
          centerPressed=true;
          return 5;
          }
      }

      if(gpio_get(inCenter)==1)
      {
          centerPressed=false;
      }

      //
      return 0;
    }

    int con_joyContin()
    {

      if(gpio_get(inUp)==0)
      {
          //printf("UP \n ");
          return 1;
      }

      if(gpio_get(inDown)==0)
      {
          //printf("DOWN \n");
          return 2;
      }

      if(gpio_get(inLeft)==0)
      {
          //printf("LEFT \n");
          return 3;
      }

      if(gpio_get(inRight)==0)
      {
          //printf("RIGHT \n");
          return 4;
      }

      if(gpio_get(inCenter)==0)
      {
          //printf("PUSH \n");
          return 5;
      }

      return 0;
    }

    int con_joyAccelerate() {
        static int lastDirection = 0;
        static uint64_t pressStartTime = 0;
        static uint64_t lastRepeatTime = 0;
        static double currentRepeatDelay = INITIAL_DELAY;

        uint64_t currentTime = to_ms_since_boot(get_absolute_time());
        int direction = con_joyContin(); // Use the existing continuous function to check current state

        if (direction != lastDirection) {
            // Direction changed or button released
            lastDirection = direction;
            if (direction != 0) {
                // New direction pressed
                pressStartTime = currentTime;
                lastRepeatTime = currentTime;
                currentRepeatDelay = INITIAL_DELAY;
                return direction;
            }
        } else if (direction != 0) {
            // Same direction held
            uint64_t holdTime = currentTime - pressStartTime;

            if (holdTime >= INITIAL_DELAY) {
                // Check if it's time for a repeat
                if (currentTime - lastRepeatTime >= currentRepeatDelay) {
                    lastRepeatTime = currentTime;

                    // Accelerate the repeat rate
                    currentRepeatDelay *= ACCELERATION_RATE;
                    if (currentRepeatDelay < MIN_REPEAT_DELAY) {
                        currentRepeatDelay = MIN_REPEAT_DELAY;
                    }

                    return direction;
                }
            }
        }

        return 0; // No input to report
    }

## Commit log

2026-02-19 Add initial assembly guide content
2026-02-19 assembly guide placeholder
    Added detailed assembly instructions and images for components including joystick and screen.
2026-02-20 Update assembly guide with additional instructions
    Added instructions for joystick cap, battery orientation, and firmware flashing process.
2026-04-12 Build documentation update to clarify the joystick footprint misalignment
2026-07-20 Replace broken firmware link with source
    [Controls.cpp, IO.cpp, Squigl.h]
